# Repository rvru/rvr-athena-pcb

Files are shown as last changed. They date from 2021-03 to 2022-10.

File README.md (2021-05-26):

# RVR Athena PCB
**Contributor(s):** Jennifer Hellar 

**Contact(s):** jennifer.hellar@rice.edu

### Revisions
#### Rev. 0.1 (r0p1)
An initial (un-manufactured) design featuring a simplified version of the HiFive
reference design without the WiFi module and a new LiPo battery charger and
connector to enable IoT prototyping.

### Reference Designs
- SiFive HiFive Rev. B
- Sparkfun RED-V RedBoard
- Adafruit Feather M0 Bluefruit LE

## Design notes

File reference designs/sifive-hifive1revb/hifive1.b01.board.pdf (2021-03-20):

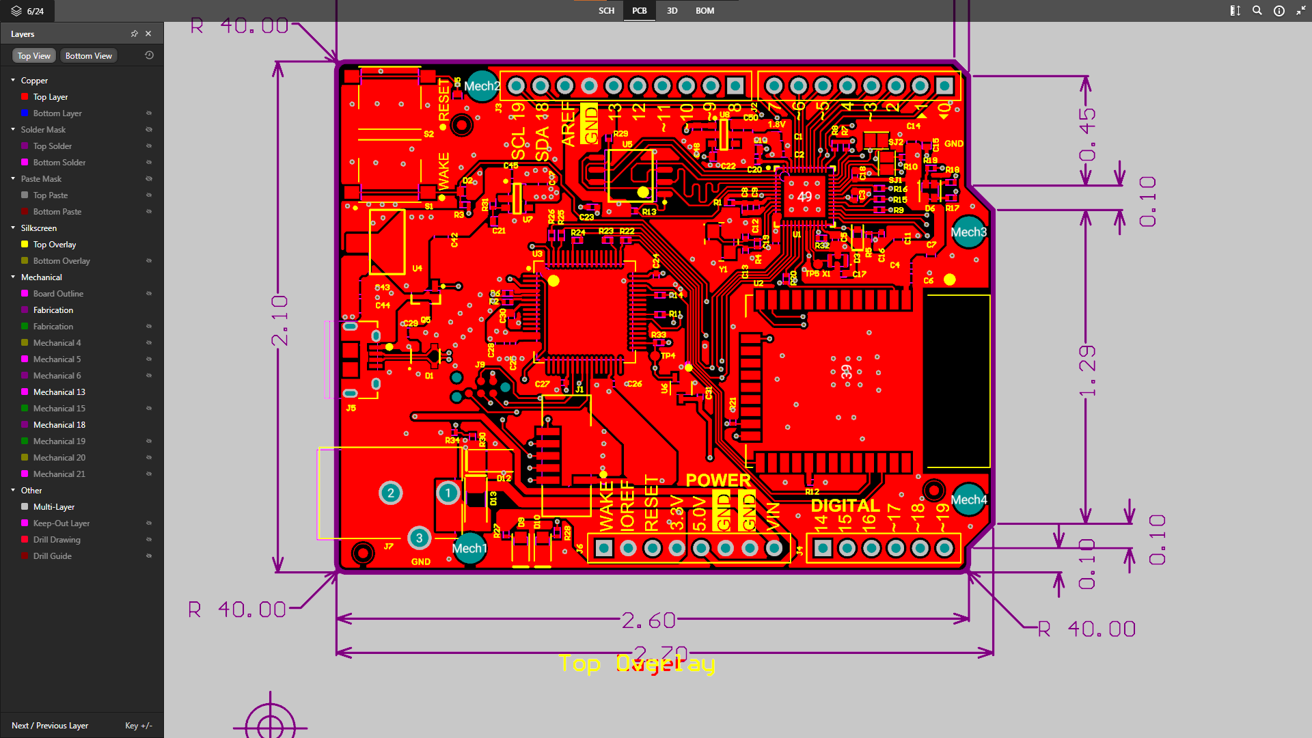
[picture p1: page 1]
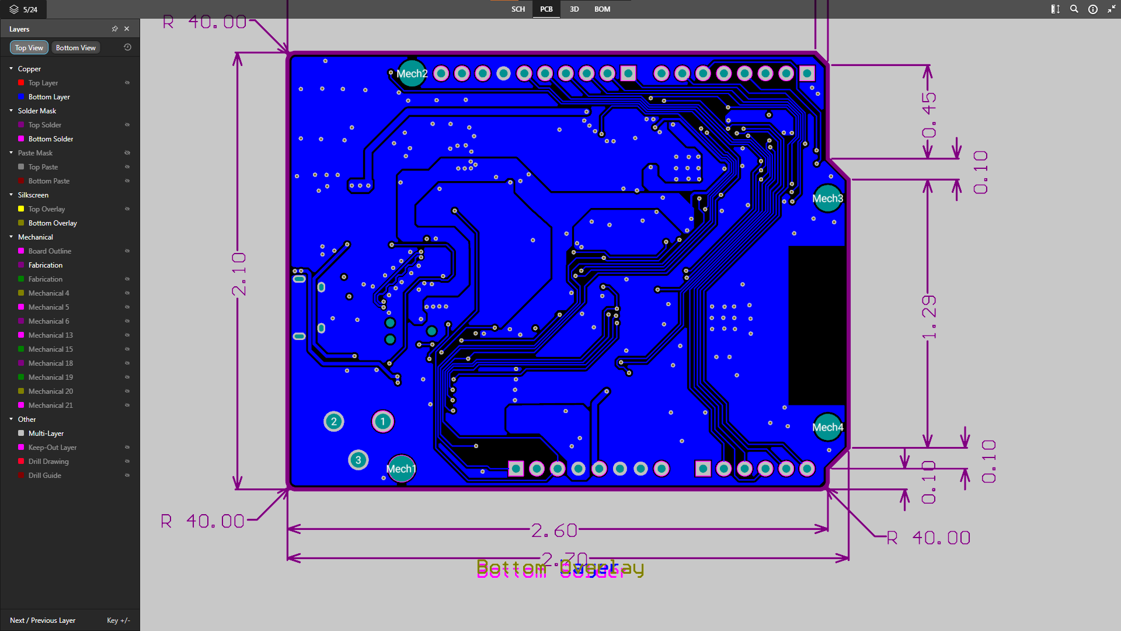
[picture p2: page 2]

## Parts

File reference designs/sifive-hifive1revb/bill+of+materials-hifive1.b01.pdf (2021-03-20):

Bill of Materials | HiFive1.B01.PrjPCB
Source Data From: | HiFive1.B01.PrjPCB
Project: | | HiFive1.B01.PrjPCB
Variant: | | None
Creation Date: 28-Feb-19 | 16:40:37
Print Date: | 15-Mar-19 | 1:10:20 AM
Item # | Quantity 10 | Manufacturer Murata | Manufacturer PN | Description | Value | Designator 1
| | Electronics | GRM188R61A106KE69J | CAP CER 10UF 10V X5R 0603 | 10uF | C1, C6, C7, C10, C11, C14, C15, C22, C28, C29
2 | 17 | Samsung Electro-Mechanics | CL05B104KO5NFNC | 0.10µF 16V Ceramic Capacitor X7R 0402 | 0.1uF | C2, C3, C4, C5, C8, C9, C17, C18, C19, C20, C23, C24, C25, C26, C27, C30, C31
3 | 2 | Yageo | CC0402JRNPO9BN150 | CAP CER 15PF 50V C0G/NPO 0402 | 15pF | C12, C13
4 | 1 | Samsung Electro-Mechanics | CL05B103KB5VPNC | CAP CER 10000PF 50V X7R 0402 | 10nF | C16
5 | 1 | Murata Electronics | GRM21BR60J226ME39L | 22µF 6.3V Ceramic Capacitor X5R 0805 | 22uF | C42
6 | 2 | Murata Electronics | GRM21BR61E106KA73L | 10µF ±10% 25V Ceramic Capacitor X5R 0805 | 10uF | C43, C44
7 | 4 | Murata Electronics | GRM188R61C105KA93D | 1µF 16V Ceramic Capacitor X5R 0603 | 1uF | C45, C47, C48, C50
8 | 1 | Nexperia | PRTR5V0U2X,215 | TVS DIODE 5.5V SOT143B | PRTR5V0U 2X,215 | D1
9 | 2 | Littlefuse | PESD0603-240 | TVS Diode 24VWM 45VClamp | PESD0603-240 | D2, D5
10 | 1 | Diodes Incorporated | 1N4148WT-7 | Diode Standard 80V 125mA Surface Mount SOD-523 | 1N4148WT- 7 | D3
11 | 1 | Lite-on Inc. | LTST-C19HE1WT | Red, Green, Blue (RGB) 624nm Red, 525nm Green, 470nm Blue LED Indication - Discrete 1.8V Red, 2.8V Green, 2.8V Blue 0606 | RGB | D6
12 | 2 | OSRAM Opto Semiconductors Inc | LG R971-KN-1 | Green 570nm LED Indication - Discrete 2.2V 0805 | Green | D9, D10
13 | 1 | Littelfuse Inc | SMF12A | TVS DIODE 12VWM 19.9VC SOD123 | SMF12A | D12
14 | 1 | Panasonic Electronic Components | DB2W40300L | Diode Schottky 40V 3A (DC) Surface Mount | DB2W4030 0L | D13
15 | 1 | CNC Tech | 3221-10-0300-00 | Connector Header Surface Mount 10 position 0.050" (1.27mm) | | J1
16 | 2 | Sullins Connector Solutions | PPTC081LFBN-RC | 8 Pin I/O Connector | | J2, J6
17 | 1 | Sullins Connector Solutions | PPTC101LFBN-RC | 10 Pin Connector | | J3
18 | 1 | Sullins Connector Solutions | PPTC061LFBN-RC | 6 Pin Connector | | J4
19 | 1 | Amphenol FCI | 10118194-0001LF | USB - micro B USB 2.0 Receptacle Connector 5 Position Surface Mount, Right Angle, Horizontal | | J5
20 | 1 | CUI Inc | PJ-102AH | Power Barrel Connector Jack 2.00mm ID (0.079"), 5.50mm OD (0.217") Through Hole, Right Angle | | J7
21 | 1 | Diodes Inc | DMG2305UX-13 | MOSFET P-CH 20V 4.2A SOT23 | P-Channel | Q5
22 | 8 | Yageo | RC0402FR-07100RL | RES SMD 100 OHM 1% 1/16W 0402 | 100R | R1, R11, R14, R22, R23, R24, R25, R26
23 | 2 | Yageo | RC0402FR-0733RL | RES SMD 33 OHM 1% 1/16W 0402 | 33R | R2, R6
24 | 9 | Yageo | RC0402FR-07100KL | RES SMD 100K OHM 1% 1/16W 0402 | 100K | R3, R5, R10, R13, R29, R30, R31, R33, R34
25 | 1 | Yageo | RC0402FR-071ML | RES SMD 1M OHM 1% 1/16W 0402 | 1M | R4
26 | 3 | Yageo | RC0402FR-0722RL | RES SMD 22 OHM 1% 1/16W 0402 | 22R | R9, R15, R16
27 | 2 | Yageo | RC0402FR-071KL | RES SMD 1K OHM 1% 1/16W 0402 | 1K | R12, R20
28 | 5 | Yageo | RC0402FR-07330RL | RES SMD 330 OHM 1% 1/16W 0402 | 330R | R17, R18, R19, R27, R28
29 | 1 | Yageo | RC0402FR-07150KL | RES SMD 150K OHM 1% 1/16W 0402 | 150K | R32
30 | 1 | C & K Components | PTS645SM43SMTR92 LFS | Blue Tactile Switch SPST-NO Top Actuated Surface Mount | | S1
31 | 1 | C & K Components | PTS645SK43SMTR92 LFS | Red Tactile Switch SPST-NO Top Actuated Surface Mount | | S2
32 | 1 | SiFive | FE310-G002 | SiFive Freedom E310 Microcontroller | FE310-G002 | U1
33 | 1 | Espressif Systems | ESP32-SOLO-1 | WiFi 802.11n + BT4.2 Chipset Module Single Core with PCB Antenna 18mmx25.5mm | ESP32-SOLO-1 | U2
34 | 1 | NXP USA Inc | MK22FN128VLH10 | K20 Microcontroller | MK22FN128 VLH10 | U3
35 | 1 | ON Semiconductor | NCP1117LPST50T3G | IC REG LINEAR 5V 1A SOT223 | NCP1117LP ST50T3G | U4
36 | 1 | ISSI | IS25LP032D-JBLE | IC FLASH 32MBIT 133MHZ 8SOIC 2.3 V ~ 3.6 V | 32Mbit | U5
37 | 1 | Microchip | MIC803-30D2VC3 | IC MPU SUPERVISOR SC70-3 | MIC803-30D2VC3 | U6
38 | 1 | Richtek USA | RT9080-33GJ5 | Linear Voltage Regulator IC Positive Fixed 1 Output 3.3V 600mA TSOT-23-5 | RT9080-33GJ5 | U7
39 | 1 | Richtek USA | RT9080-18GJ5 | Linear Voltage Regulator IC Positive Fixed 1 Output 1.8V 600mA TSOT-23-5 | RT9080-18GJ5 | U8
40 | 1 | SiTime | SIT1533AI-H4-DCC-32.768E | 32.768kHz LVCMOS MEMS (Silicon) Oscillator Surface Mount 1.2 V ~ 3.63 V 1.3µA | 32.768KHz | X1
41 | 1 | Epson | TSX-3225 16.0000MF18X-AC0 | 16MHz ±10ppm Crystal 9pF 60 Ohm | 16MHz | Y1
Approved | Notes
Altium Limited Confidential | 3/15/2019 | Page 1

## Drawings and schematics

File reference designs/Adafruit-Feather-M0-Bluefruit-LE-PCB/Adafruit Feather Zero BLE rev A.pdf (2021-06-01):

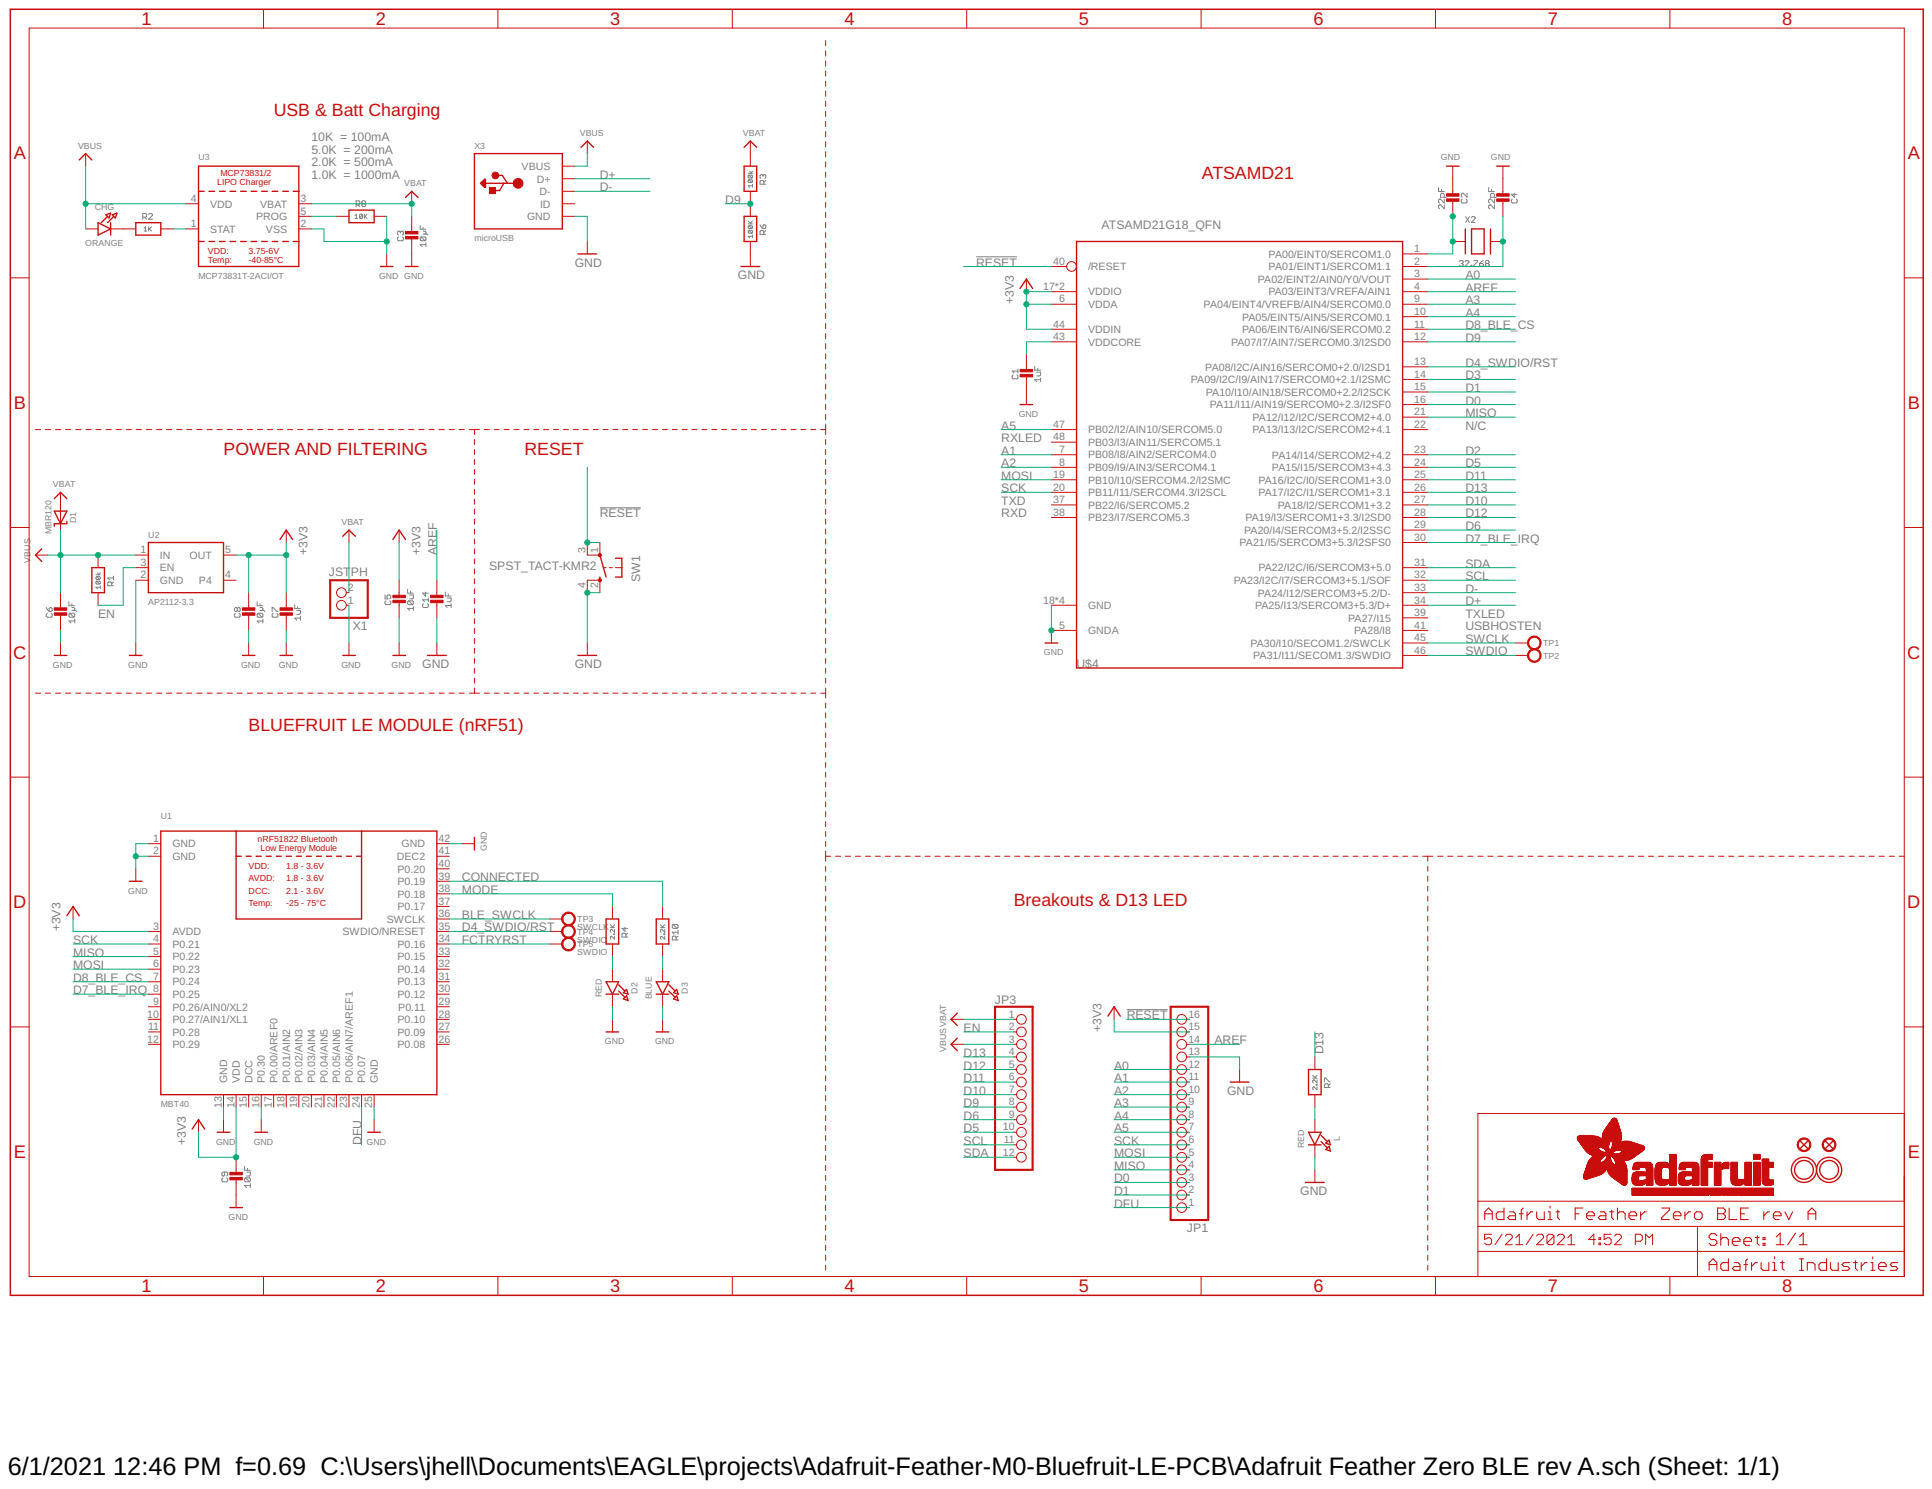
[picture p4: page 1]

6/1/2021 12:46 PM f=0.69 C:\Users\jhell\Documents\EAGLE\projects\Adafruit-Feather-M0-Bluefruit-LE-PCB\Adafruit Feather Zero BLE rev A.sch (Sheet: 1/1)

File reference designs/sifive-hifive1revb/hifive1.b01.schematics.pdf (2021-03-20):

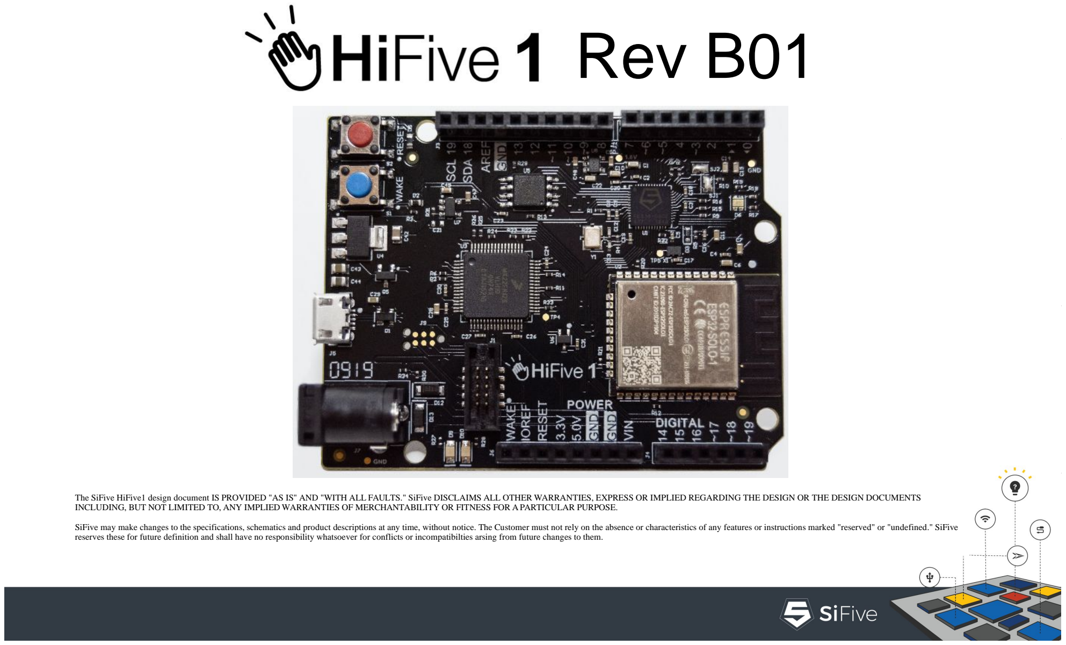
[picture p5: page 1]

The SiFive HiFive1 design document IS PROVIDED "AS IS" AND "WITH ALL FAULTS." SiFive DISCLAIMS ALL OTHER WARRANTIES, EXPRESS OR IMPLIED REGARDING THE DESIGN OR THE DESIGN DOCUMENTS
INCLUDING, BUT NOT LIMITED TO, ANY IMPLIED WARRANTIES OF MERCHANTABILITY OR FITNESS FOR A PARTICULAR PURPOSE.

SiFive may make changes to the specifications, schematics and product descriptions at any time, without notice. The Customer must not rely on the absence or characteristics of any features or instructions marked "reserved" or "undefined." SiFive
reserves these for future definition and shall have no responsibility whatsoever for conflicts or incompatibilties arsing from future changes to them.

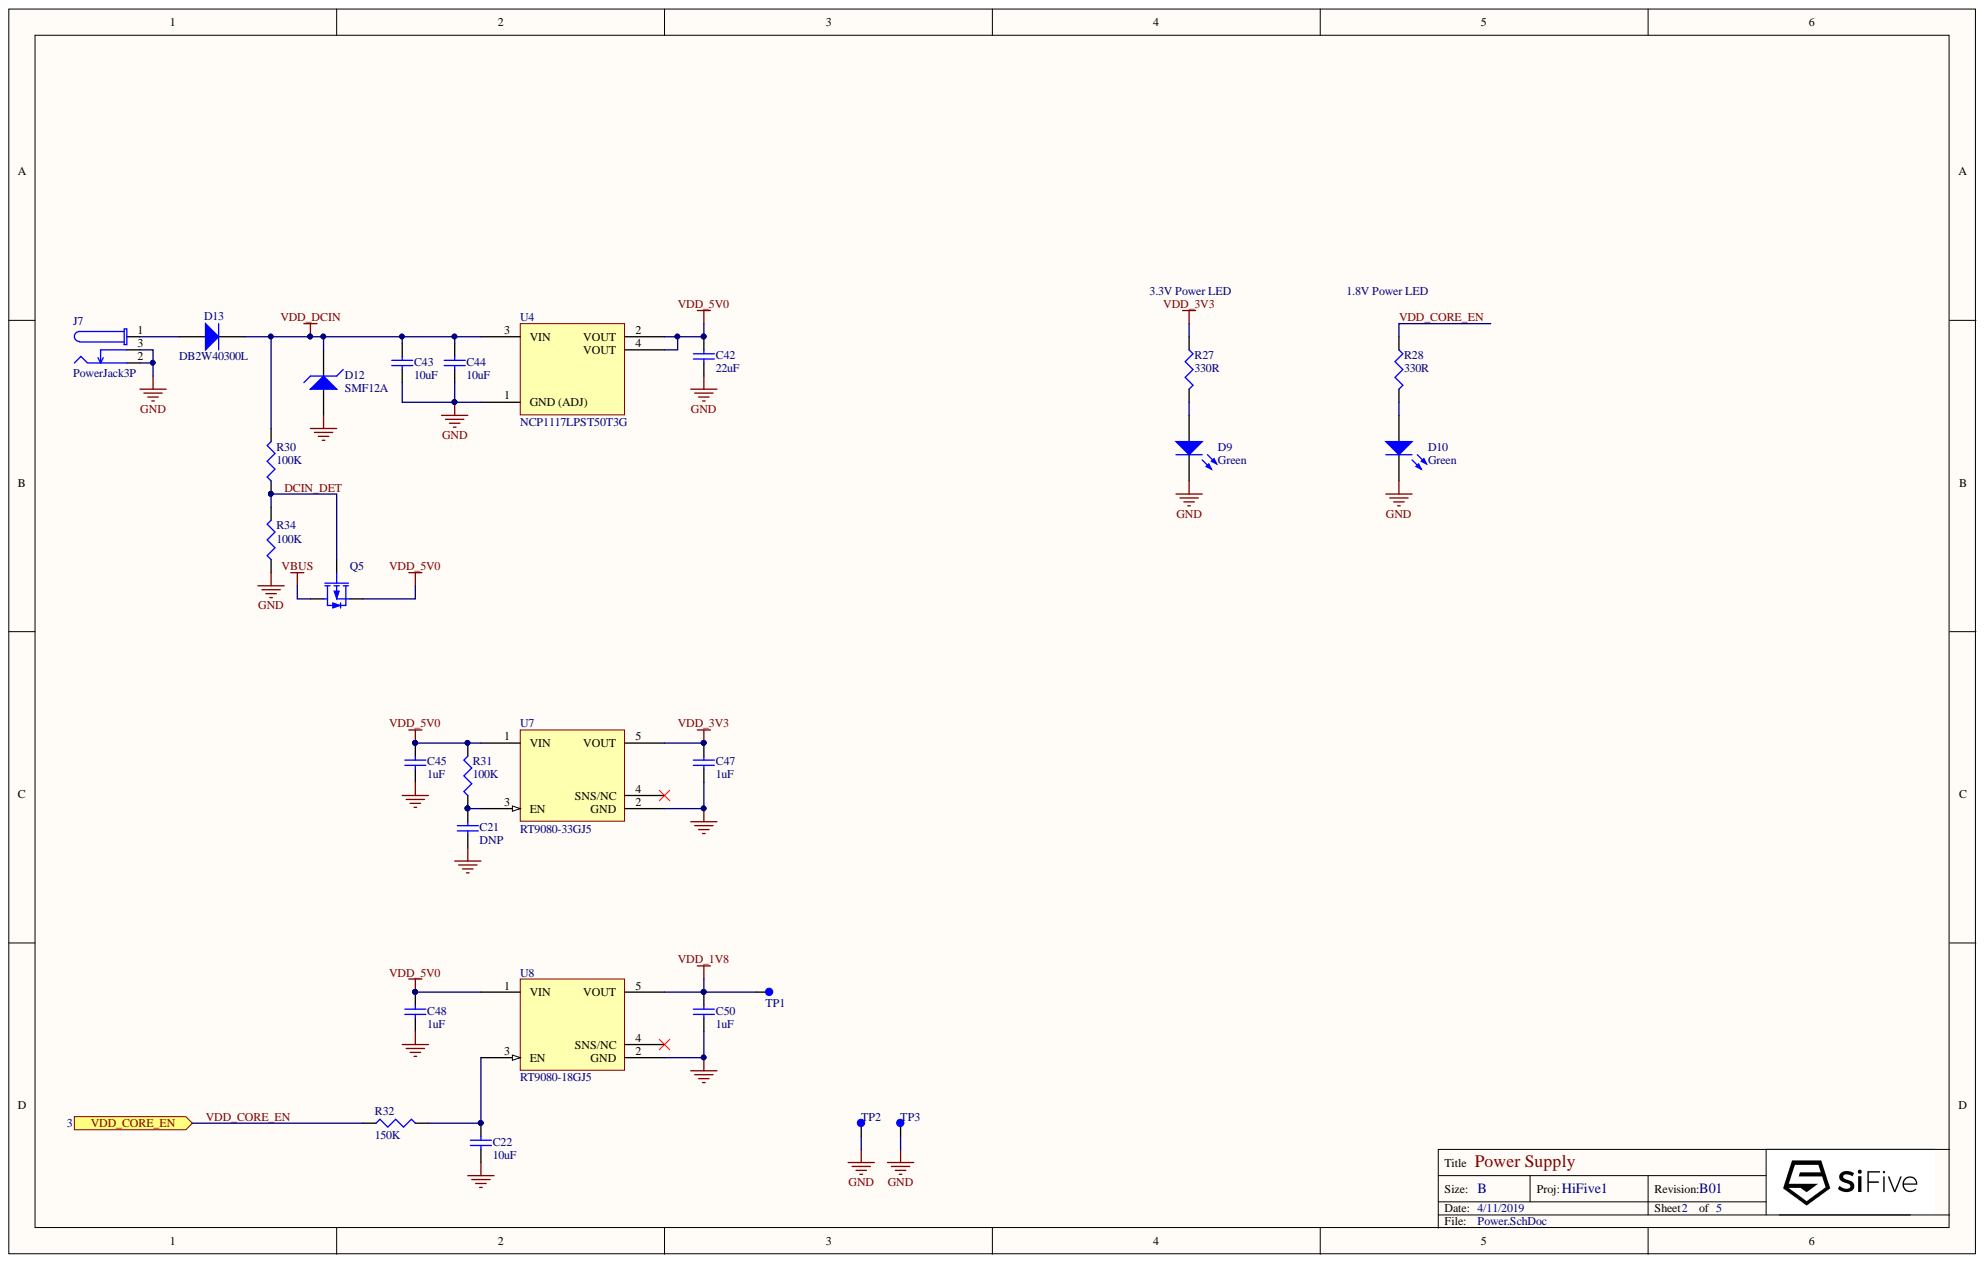
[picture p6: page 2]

Power Supply Title

B Size: | HiFive1 Proj: | B01 Revision:

Date: 4/11/2019 | | Sheet 2 of 5

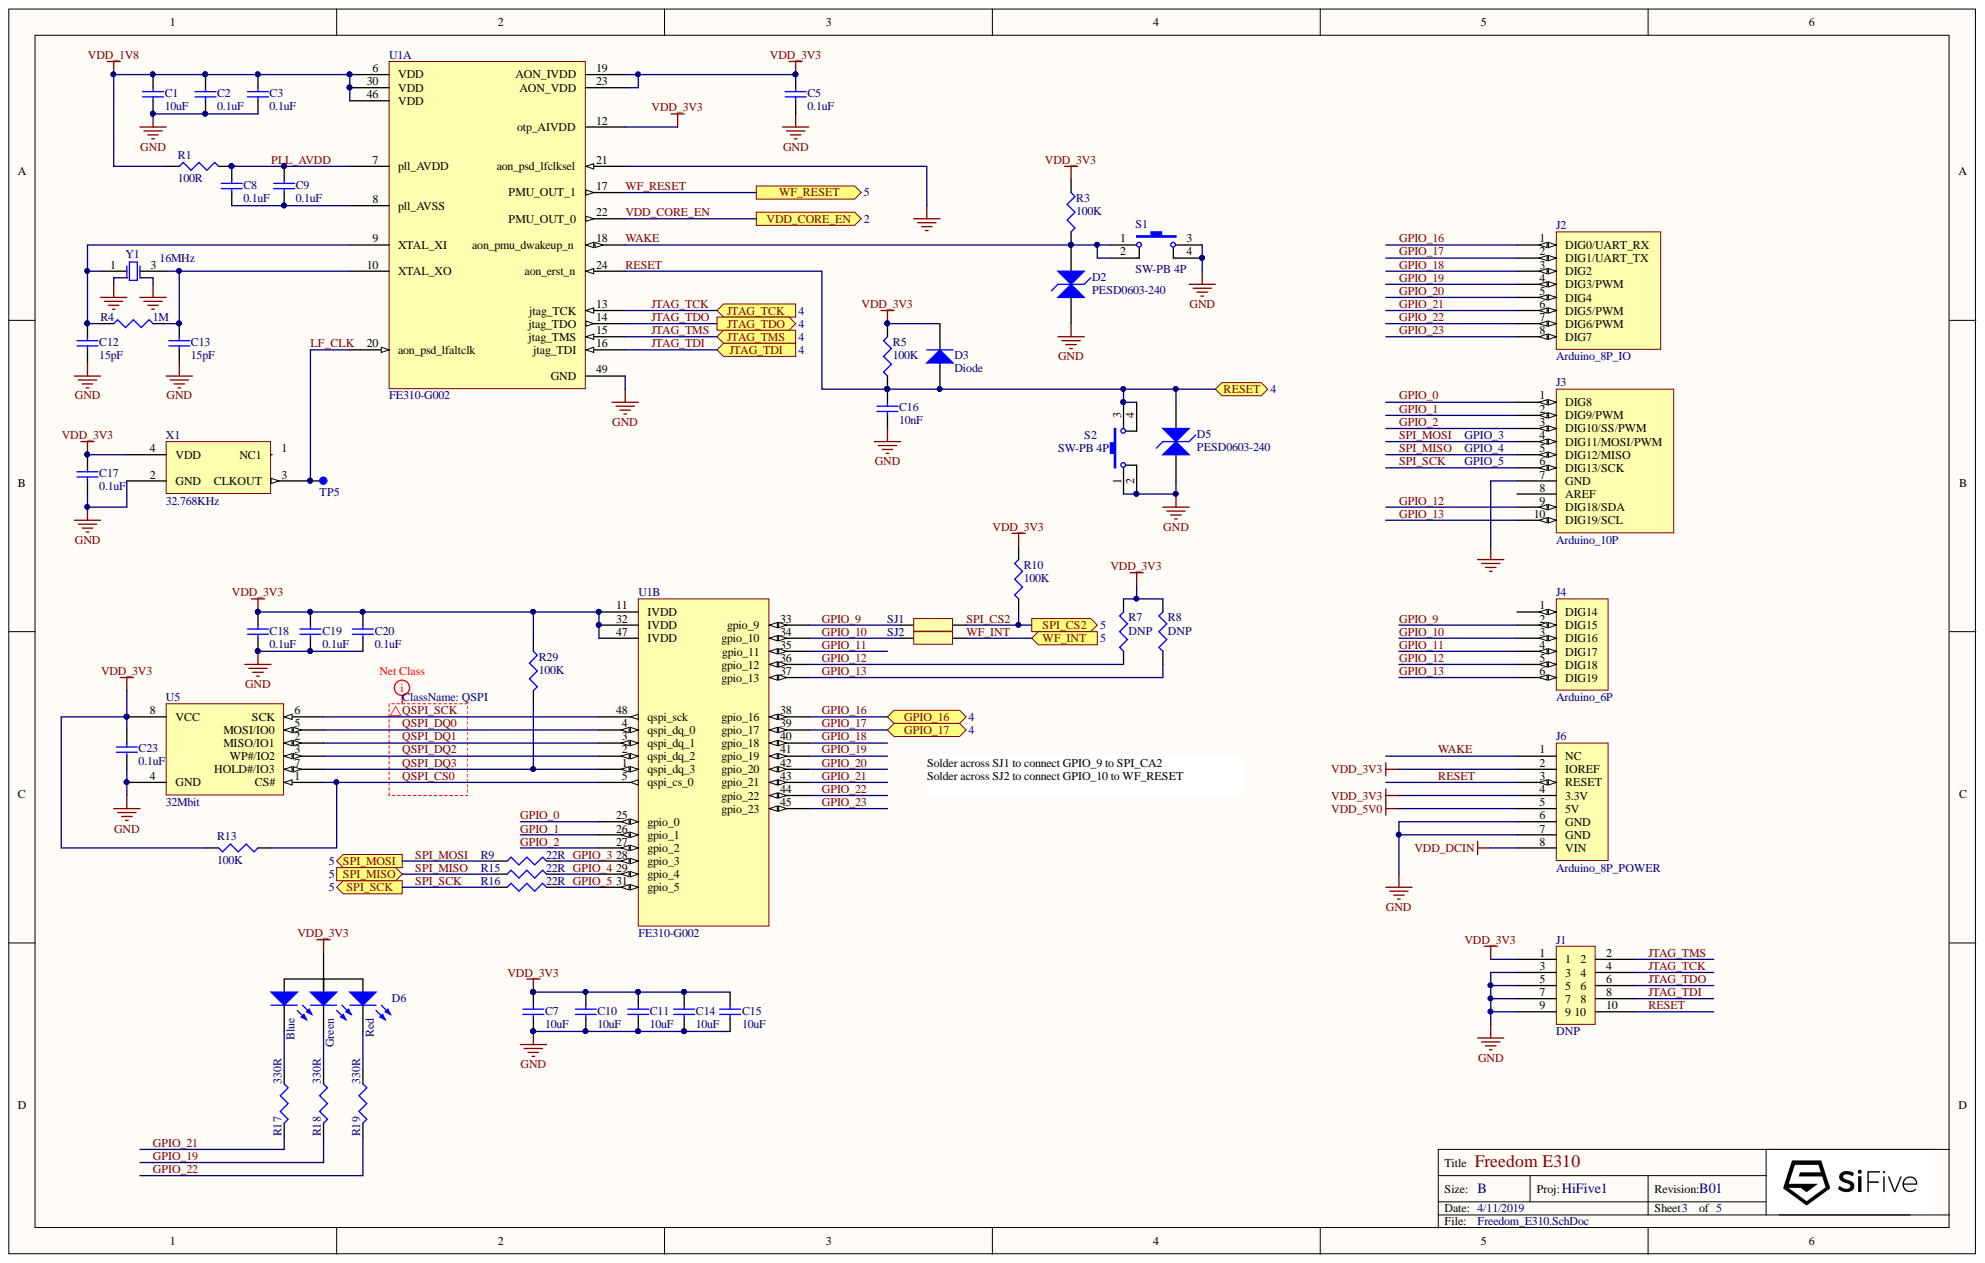
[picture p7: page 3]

0.1uF | | pll_AVDD 7 pll_AVSS 8

Solder across SJ1 to connect GPIO_9 to SPI_CA2
Solder across SJ2 to connect GPIO_10 to WF_RESET

gpio_0 25 gpio_1 26 gpio_2 27 gpio_3 28 gpio_4 29 gpio_5 31 | GPIO_22 | 3.3V 4

GPIO_23 | 5V 5

B Size: | HiFive1 Proj: | B01 Revision:

Date: 4/11/2019 | | Sheet 3 of 5

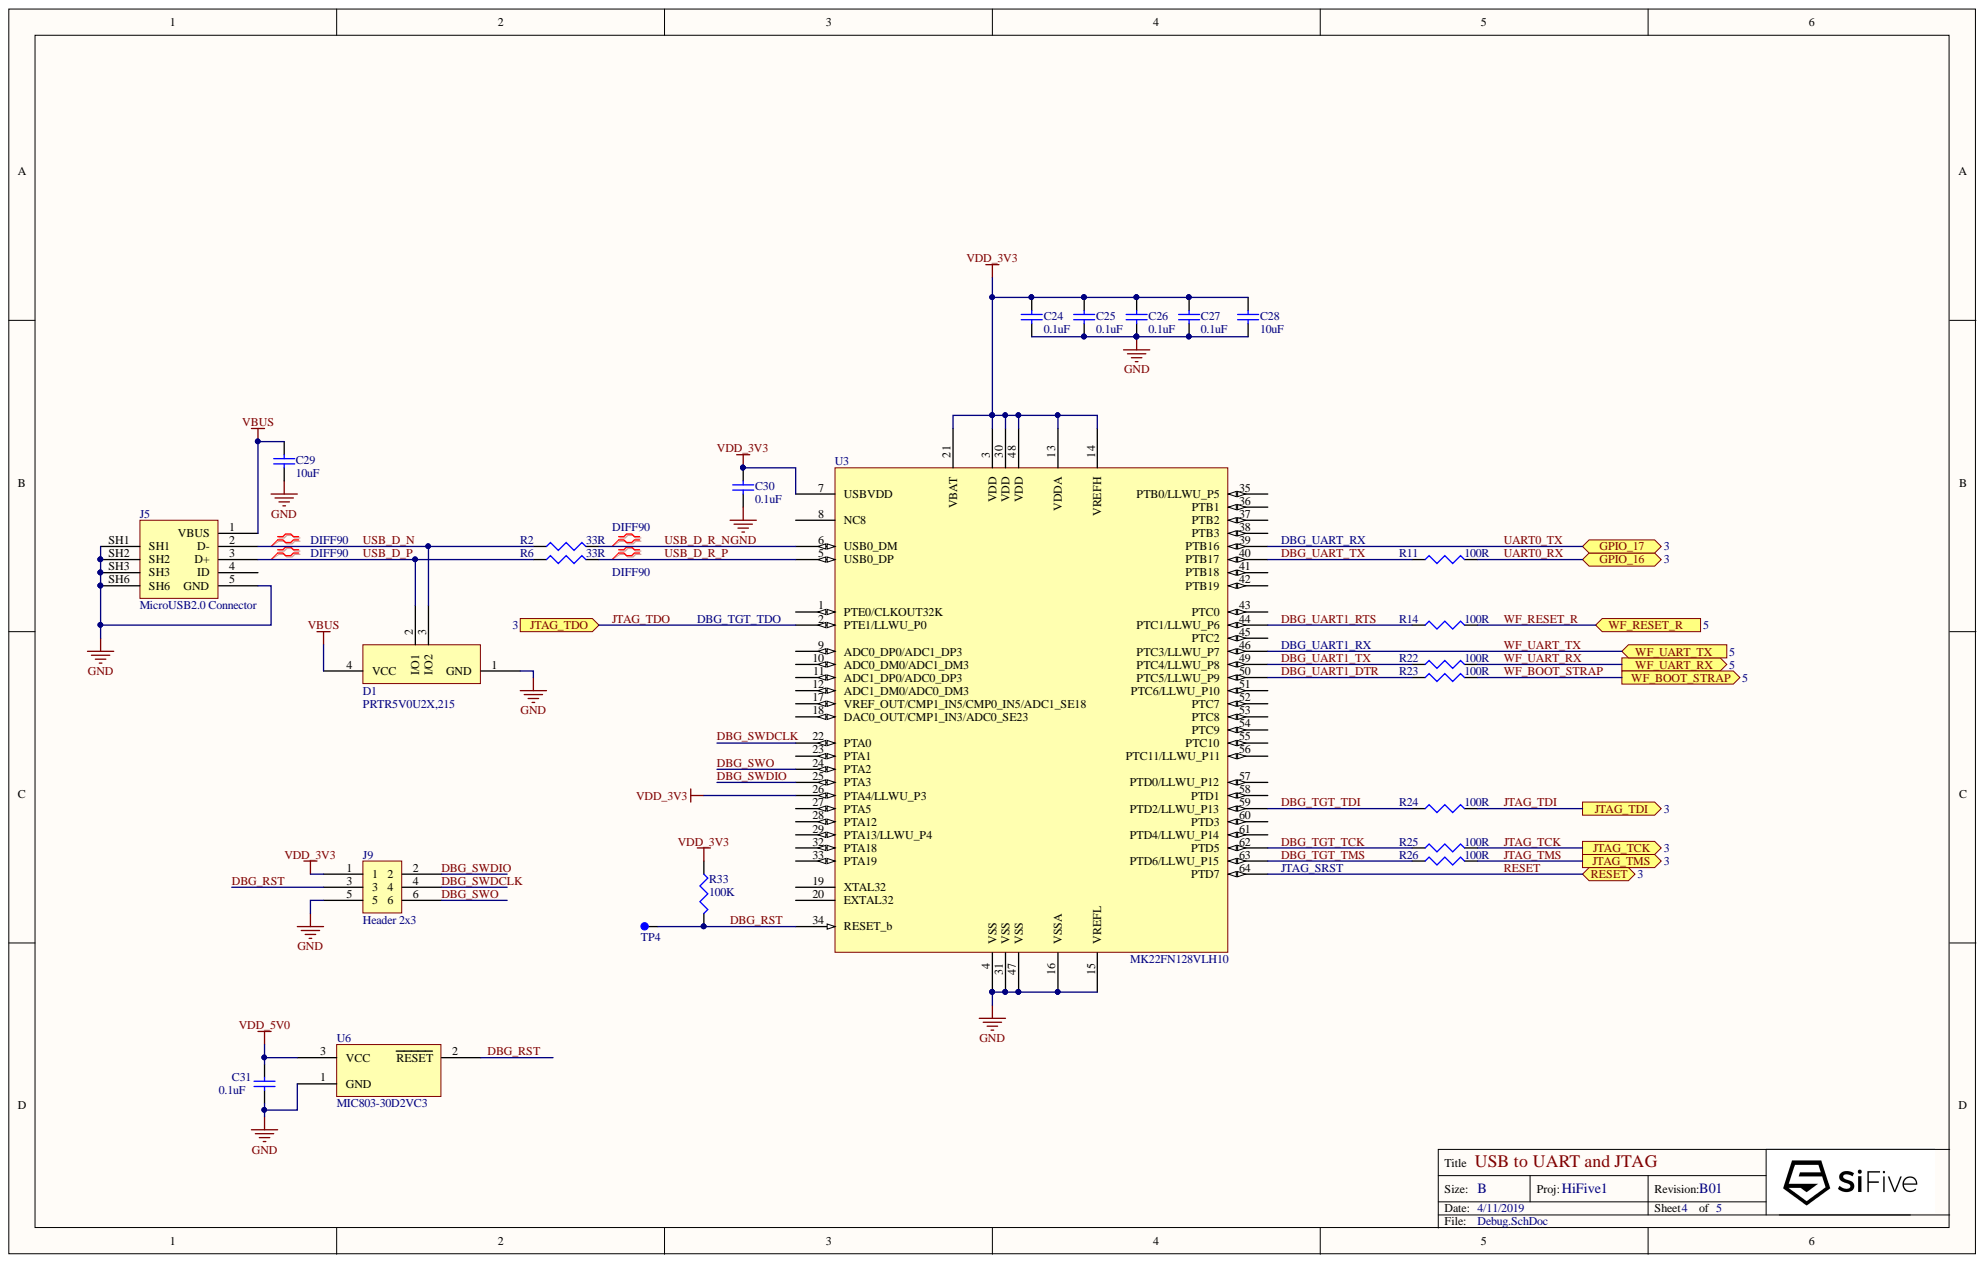
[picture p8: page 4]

USB to UART and JTAG Title

B Size: | HiFive1 Proj: | B01 Revision:

Date: 4/11/2019 | | Sheet 4 of 5

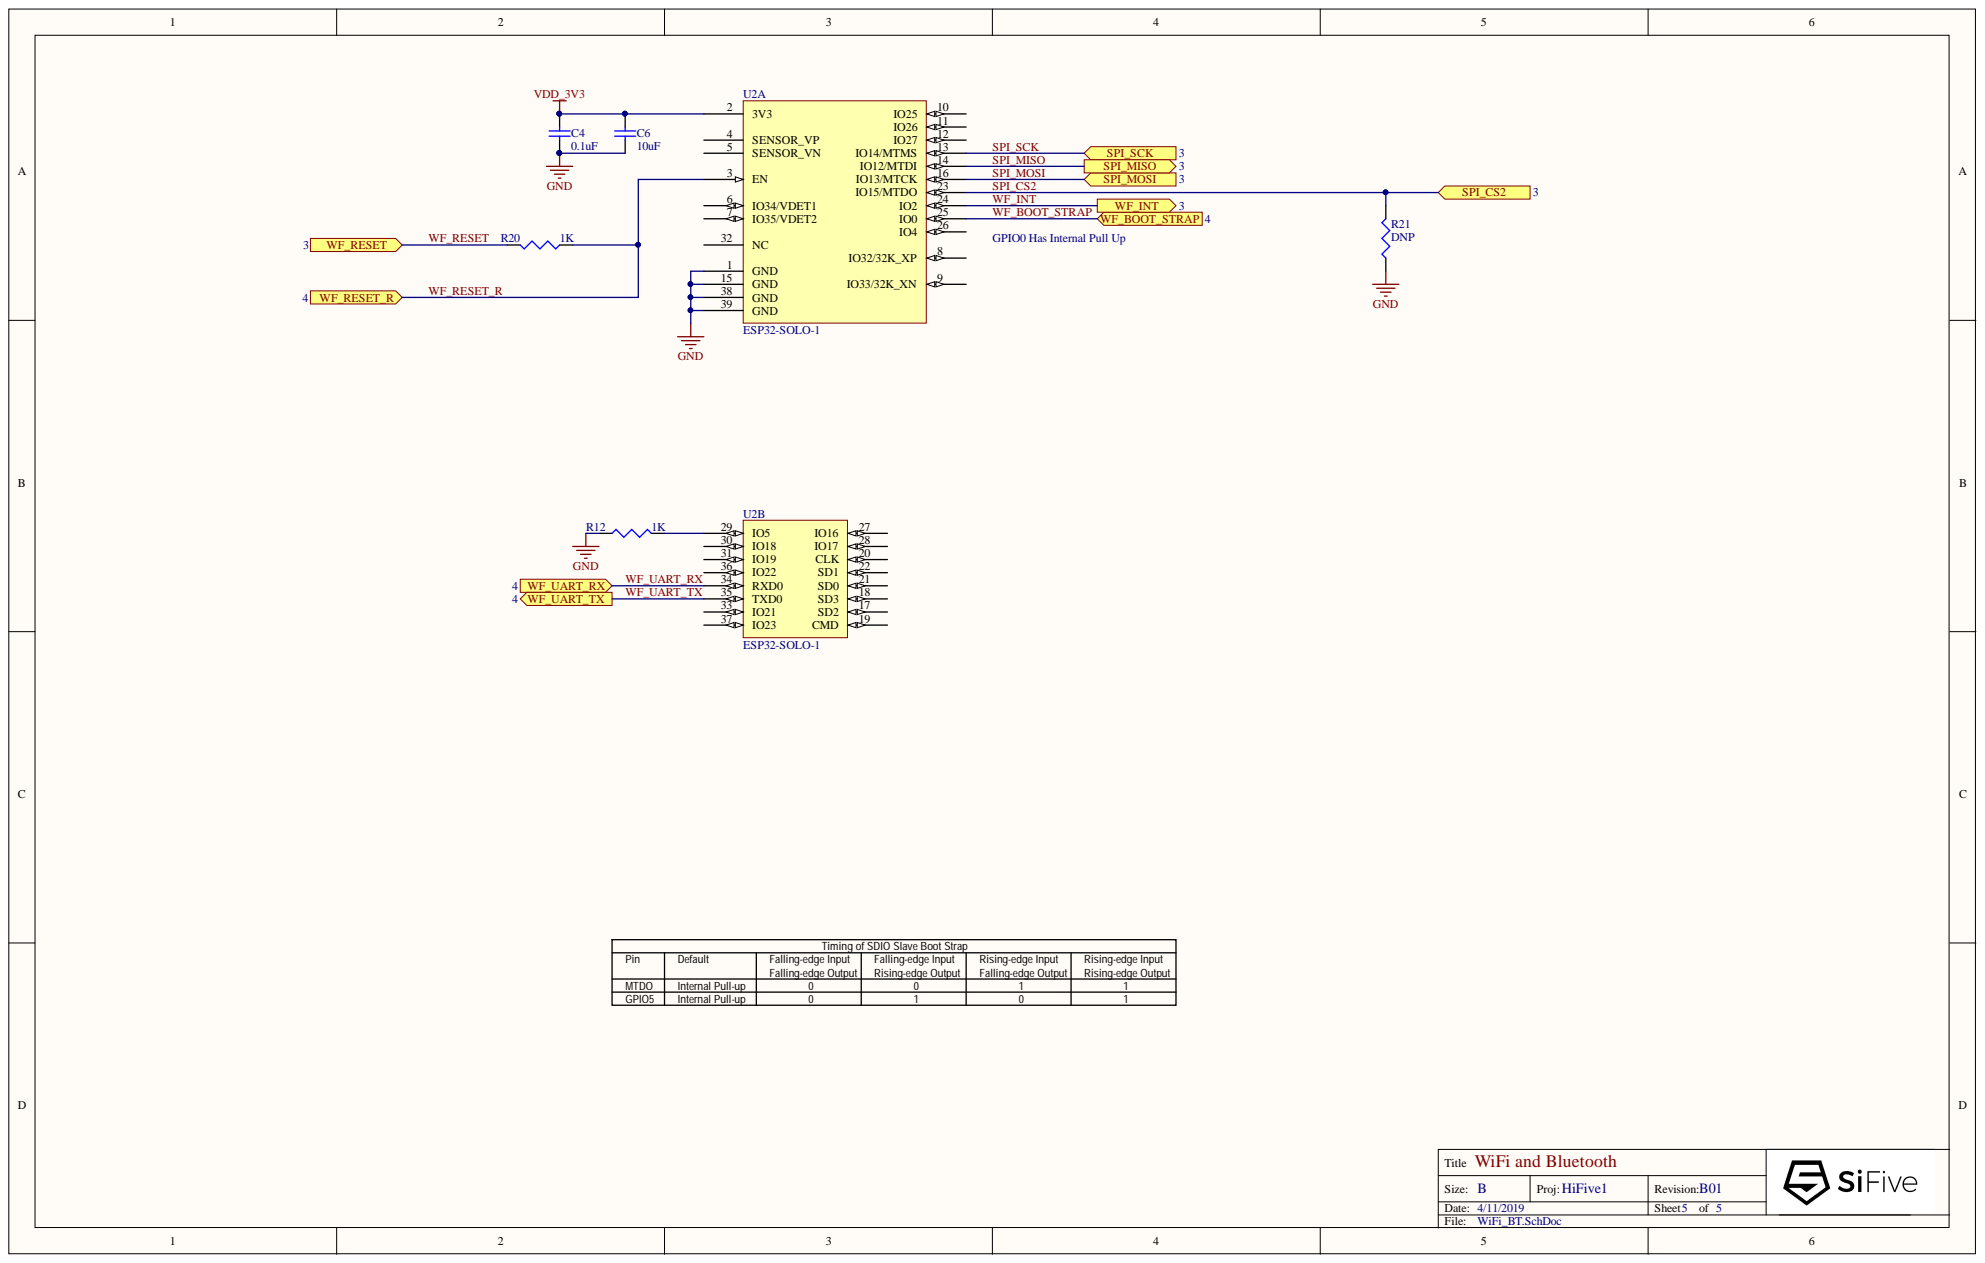
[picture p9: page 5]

GPIO0 Has Internal Pull Up

GND 1
GND 15
GND 38
GND 39

Timing of SDIO Slave Boot Strap

Pin | Default | Falling-edge Input Falling-edge Output | Falling-edge Input Rising-edge Output | Rising-edge Input Falling-edge Output | Rising-edge Input Rising-edge Output

MTDO | Internal Pull-up | 0 0 | | 1 1
GPIO5 | Internal Pull-up | 0 | 1 | 0 | 1

WiFi and Bluetooth Title

B Size: | HiFive1 Proj: | B01 Revision:

Date: 4/11/2019 | | Sheet 5 of 5

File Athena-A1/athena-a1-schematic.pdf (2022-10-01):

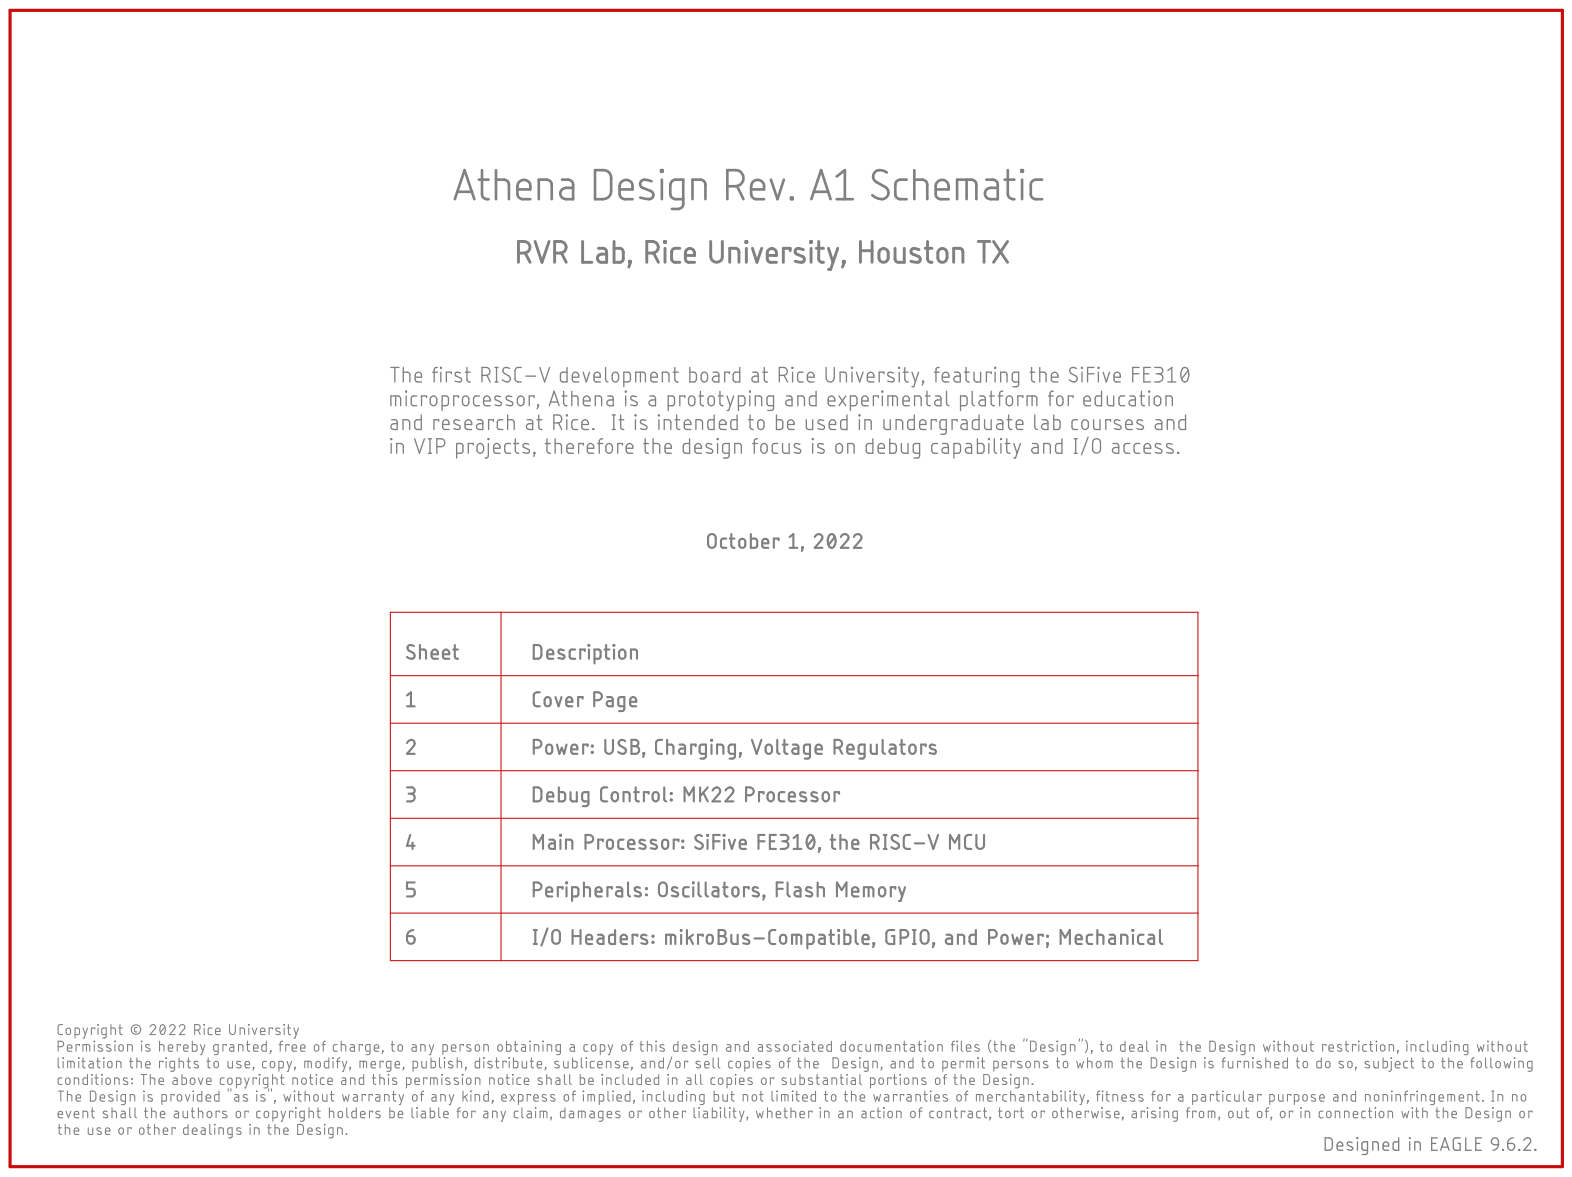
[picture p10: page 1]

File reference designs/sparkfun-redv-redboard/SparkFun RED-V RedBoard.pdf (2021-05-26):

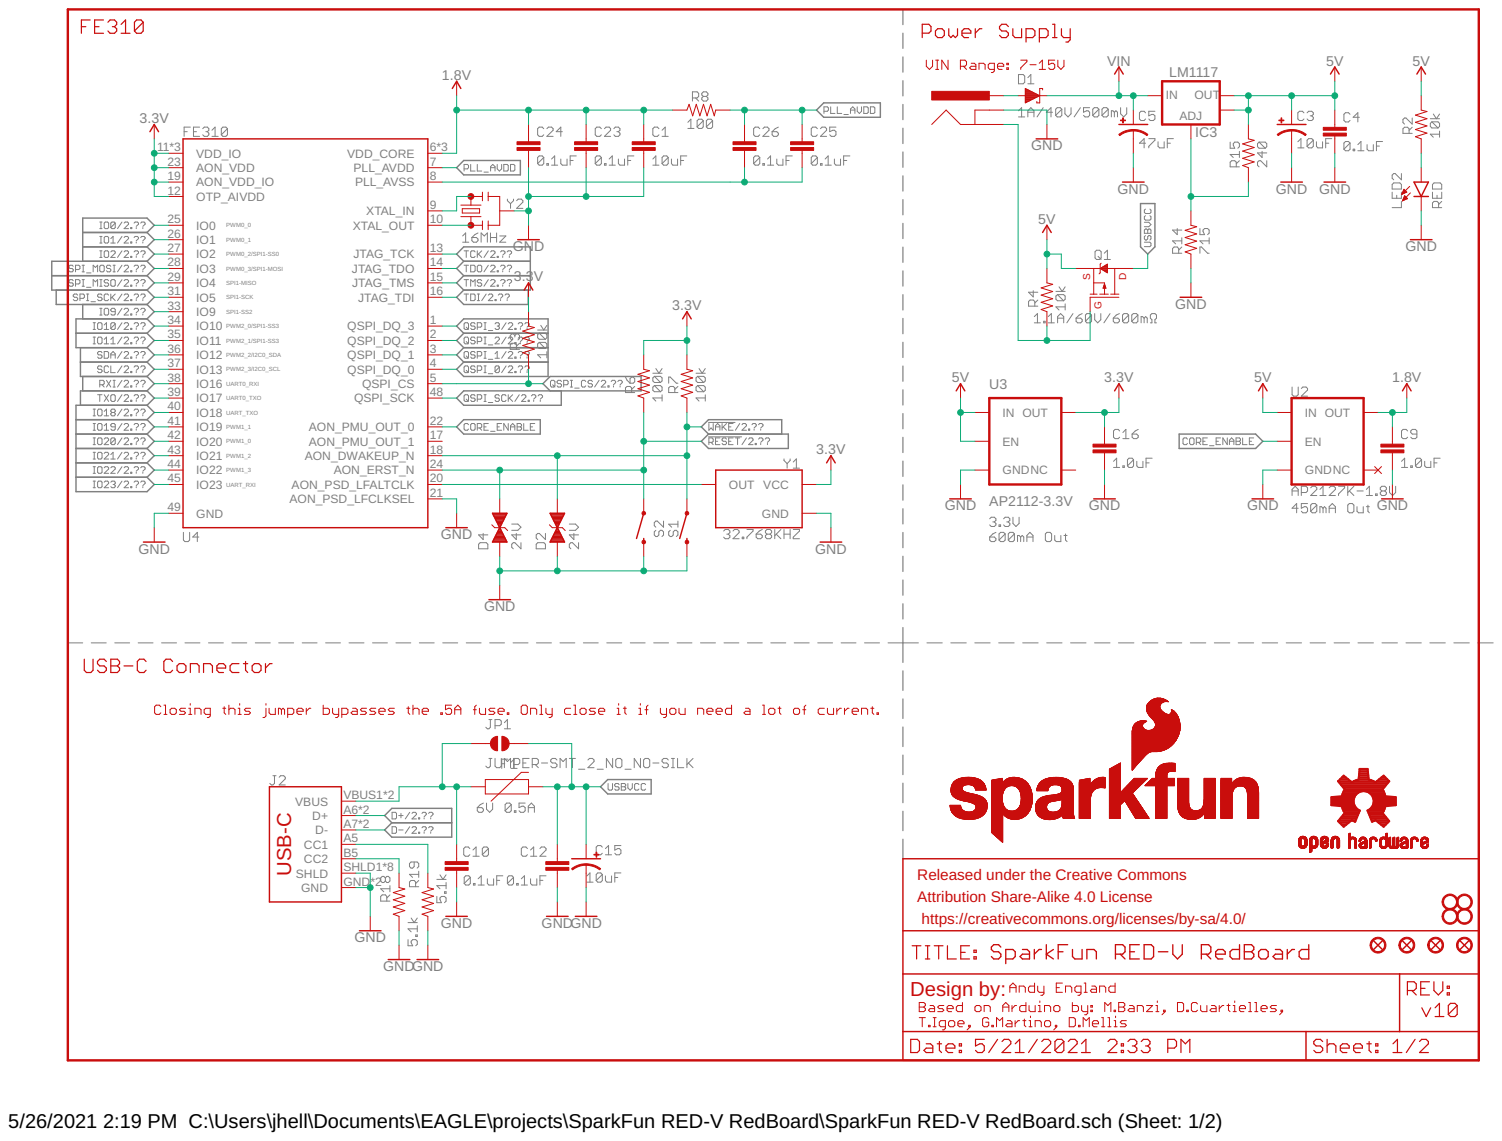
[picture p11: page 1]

Released under the Creative Commons Attribution Share-Alike 4.0 License

https://creativecommons.org/licenses/by-sa/4.0/

5/26/2021 2:19 PM C:\Users\jhell\Documents\EAGLE\projects\SparkFun RED-V RedBoard\SparkFun RED-V RedBoard.sch (Sheet: 1/2)

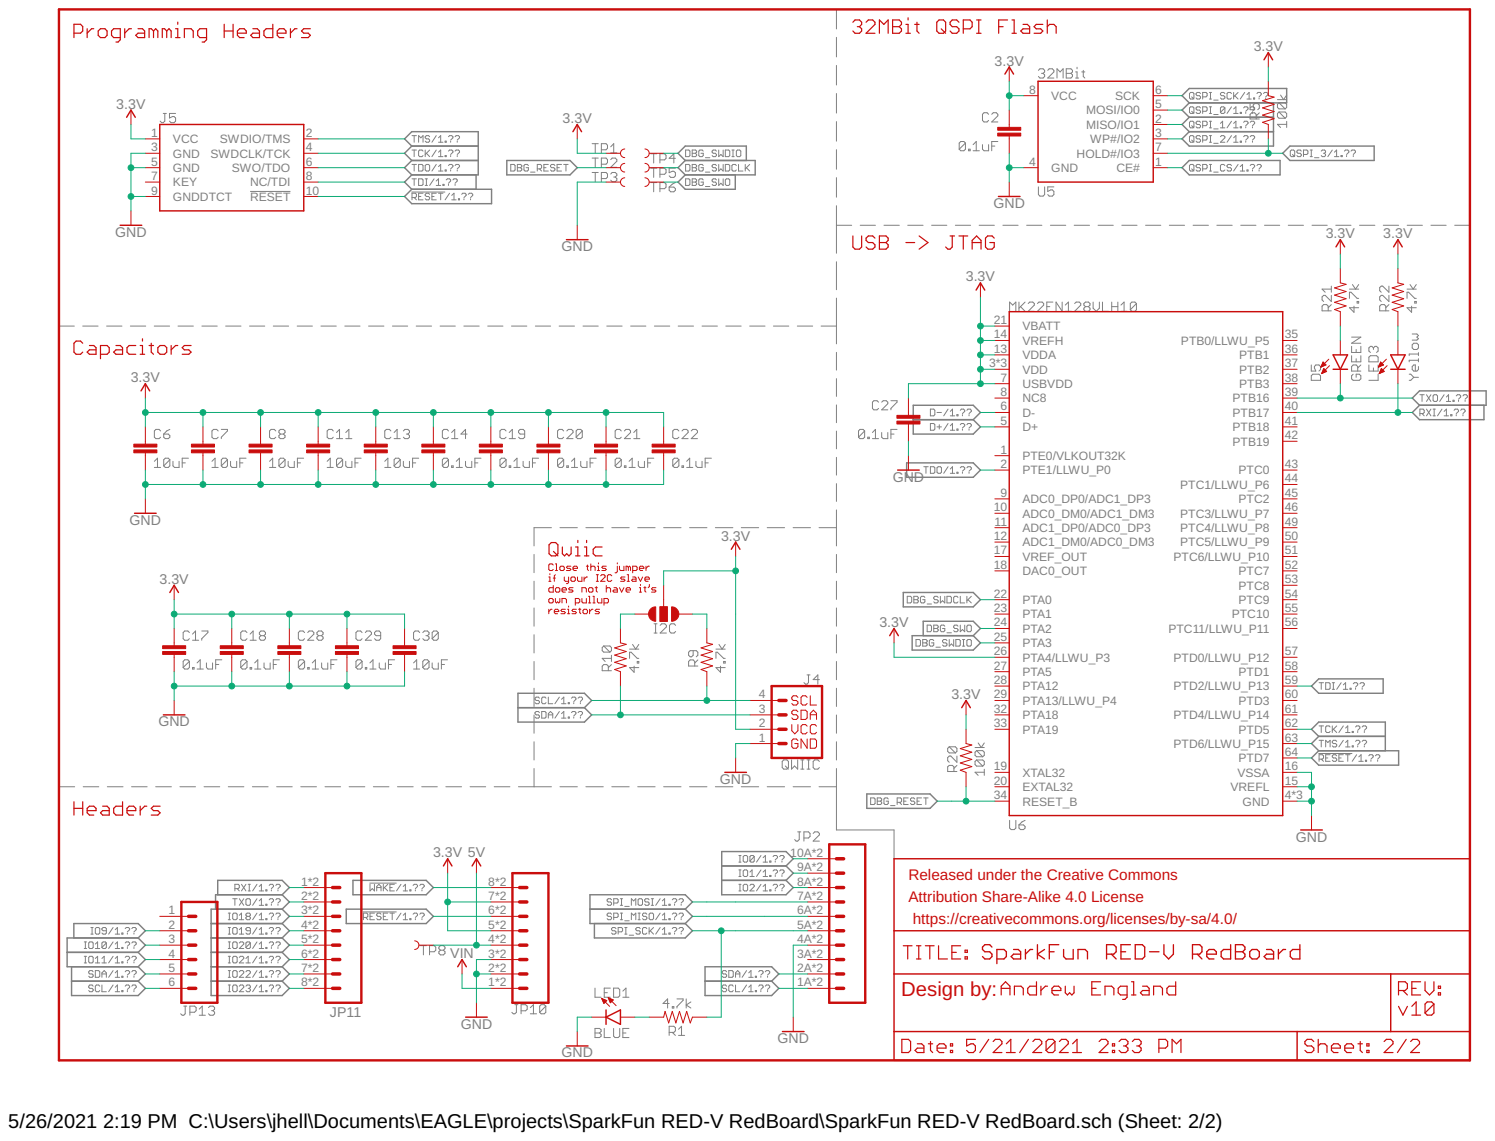
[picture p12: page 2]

Released under the Creative Commons Attribution Share-Alike 4.0 License

https://creativecommons.org/licenses/by-sa/4.0/

5/26/2021 2:19 PM C:\Users\jhell\Documents\EAGLE\projects\SparkFun RED-V RedBoard\SparkFun RED-V RedBoard.sch (Sheet: 2/2)

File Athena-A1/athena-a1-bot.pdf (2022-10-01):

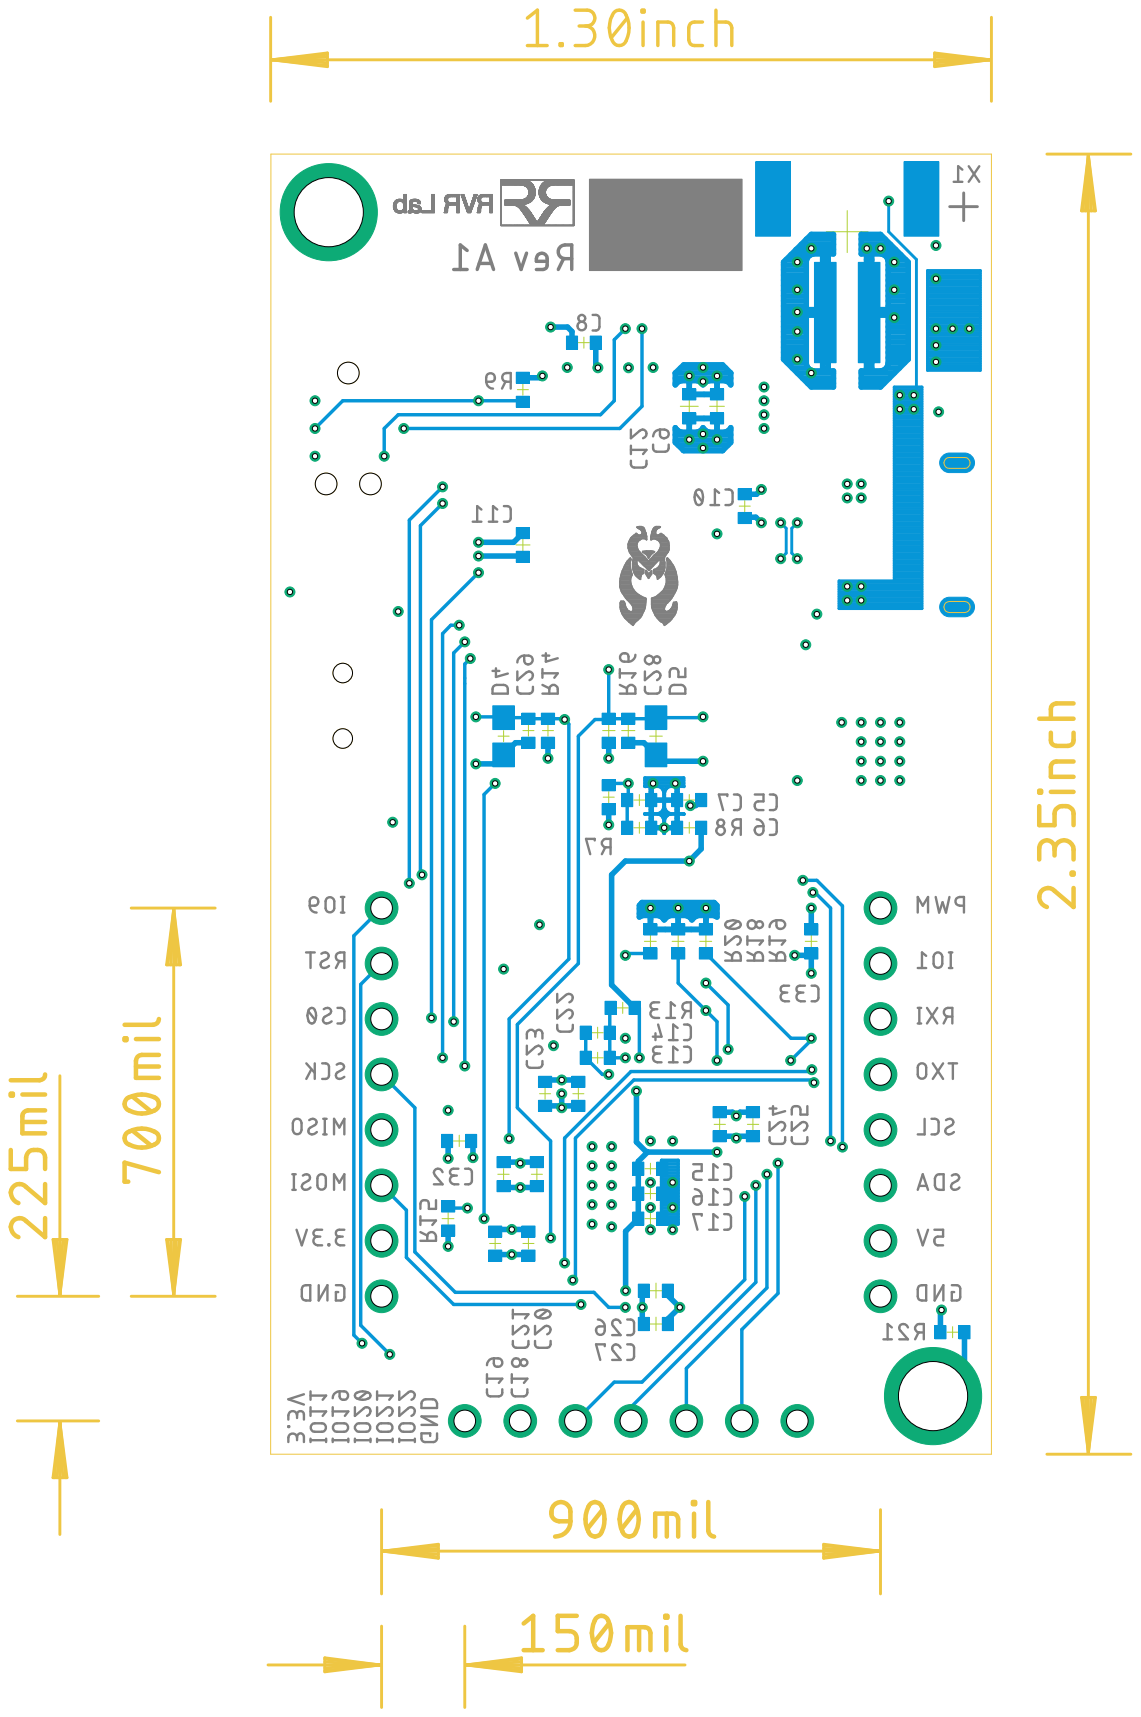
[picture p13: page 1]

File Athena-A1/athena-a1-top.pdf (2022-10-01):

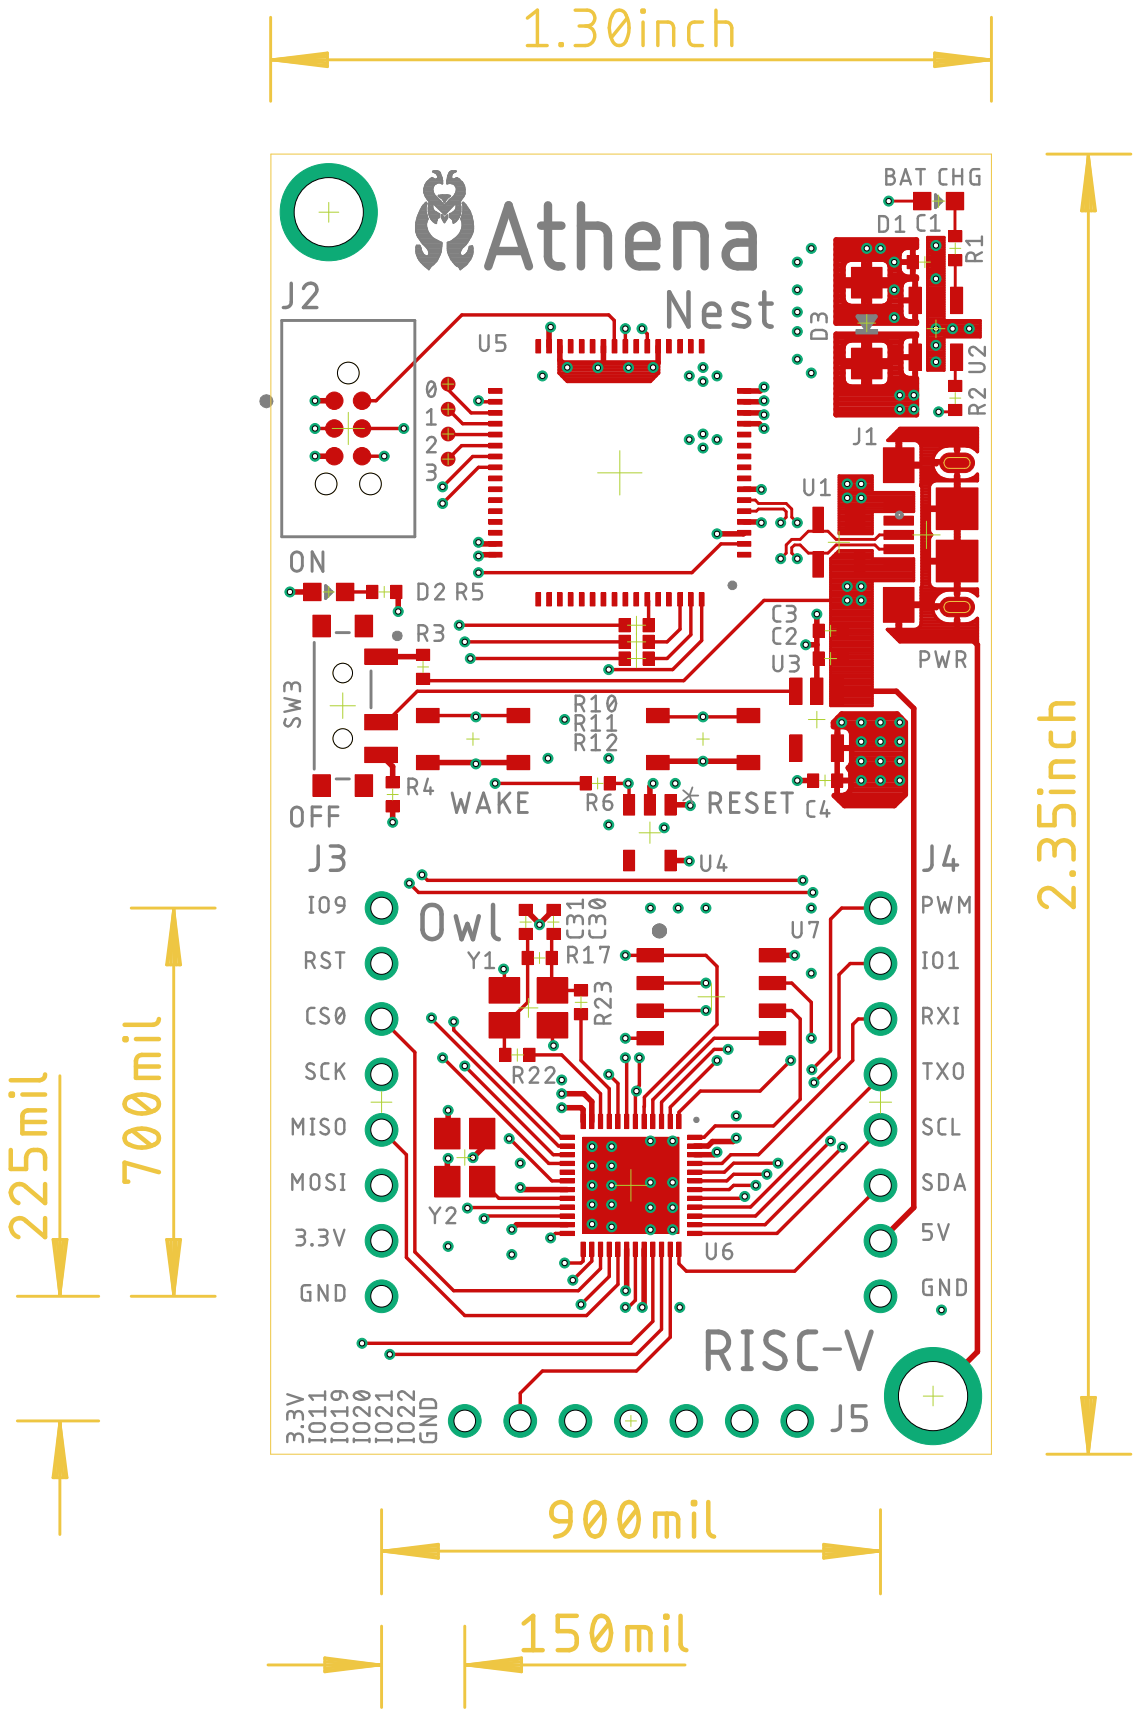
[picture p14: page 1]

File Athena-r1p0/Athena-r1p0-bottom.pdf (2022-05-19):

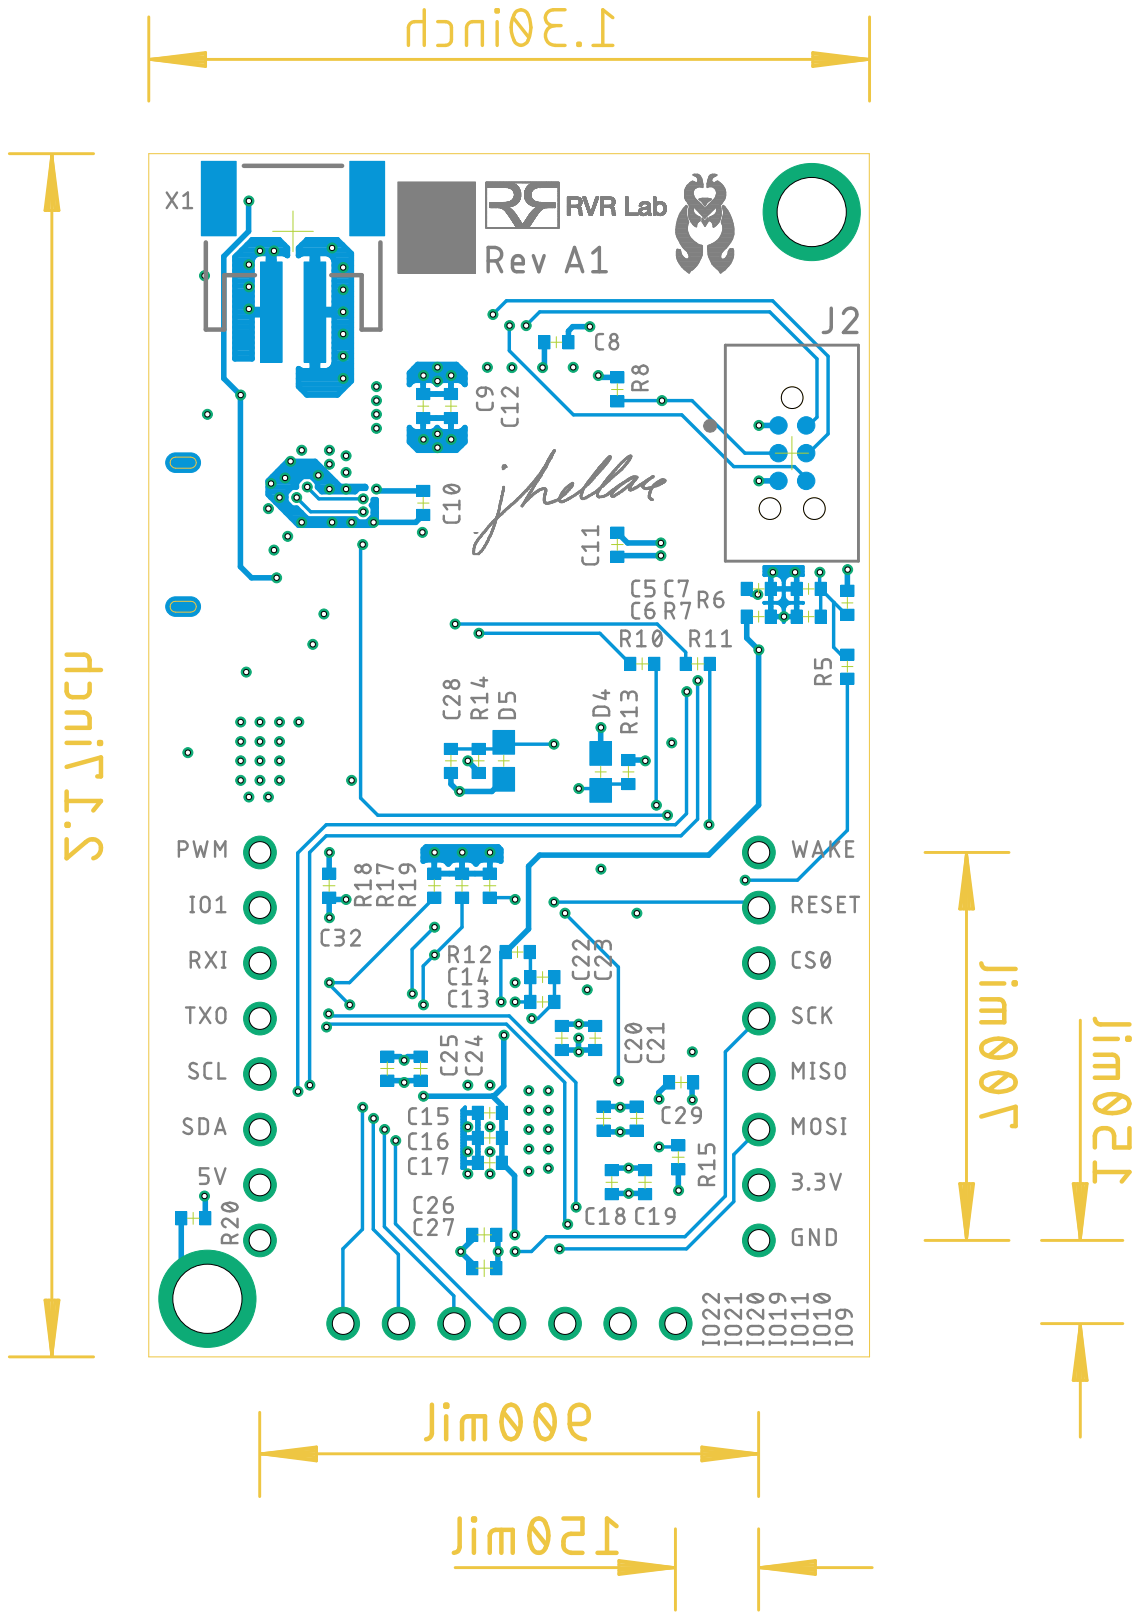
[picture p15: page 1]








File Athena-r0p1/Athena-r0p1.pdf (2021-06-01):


6/1/2021 5:34 PM C:\Users\jhell\Documents\EAGLE\projects\Athena-r0p1\Athena-r0p1.sch (Sheet: 1/5)


6/1/2021 5:34 PM C:\Users\jhell\Documents\EAGLE\projects\Athena-r0p1\Athena-r0p1.sch (Sheet: 2/5)


6/1/2021 5:34 PM C:\Users\jhell\Documents\EAGLE\projects\Athena-r0p1\Athena-r0p1.sch (Sheet: 3/5)


PLL_AVDD

6/1/2021 5:34 PM C:\Users\jhell\Documents\EAGLE\projects\Athena-r0p1\Athena-r0p1.sch (Sheet: 4/5)


6/1/2021 5:34 PM C:\Users\jhell\Documents\EAGLE\projects\Athena-r0p1\Athena-r0p1.sch (Sheet: 5/5)

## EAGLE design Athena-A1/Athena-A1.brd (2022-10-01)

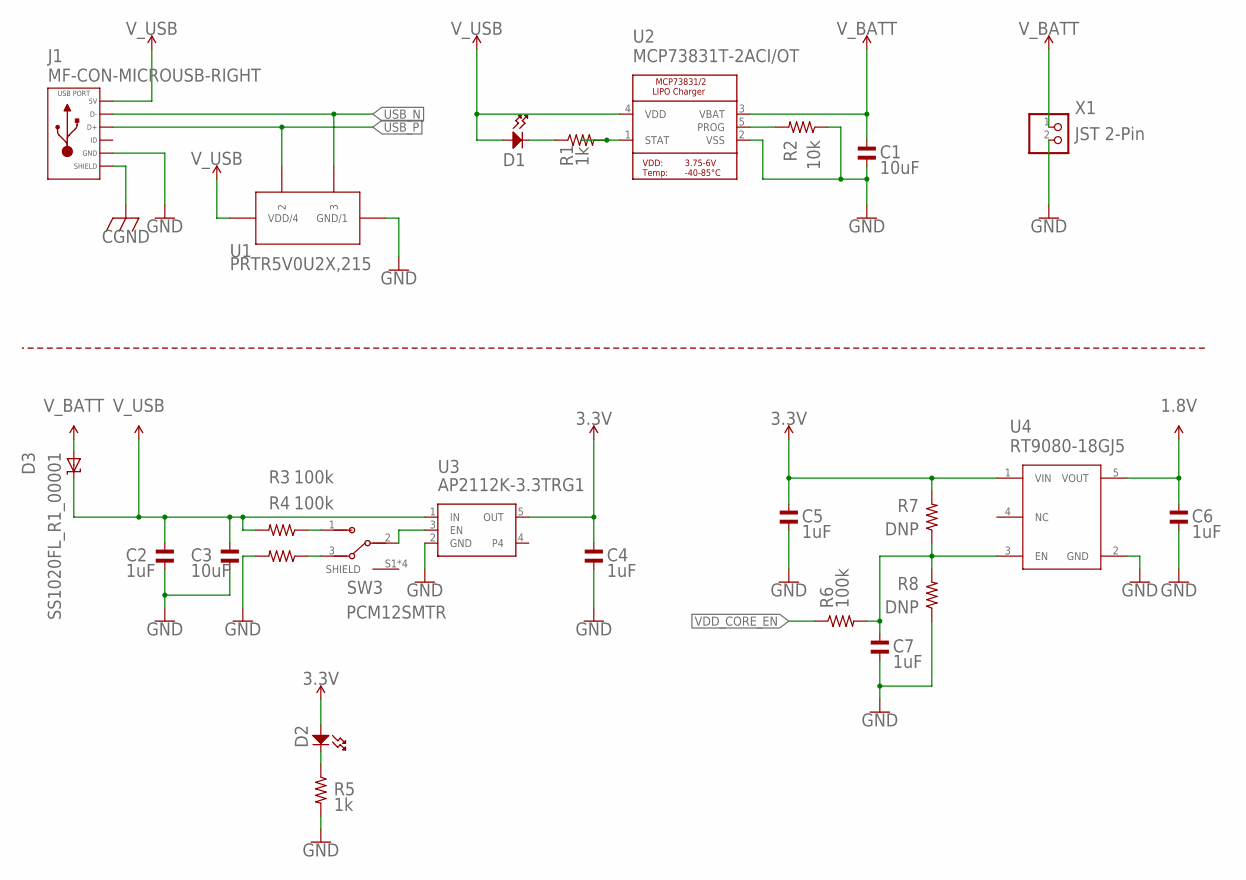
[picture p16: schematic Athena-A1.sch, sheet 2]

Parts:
C1, C3: 10uF; C0402; MPN CL05A106MP8NUB8
C2, C4, C5, C6, C7: 1uF; C0402
D1: MF-LED-0805-RED; LED0603
D2: MF-LED-0603-GREEN; LED0603
D3: SS1020FL_R1_00001; SOD-123
J1: MF-CON-MICROUSB-RIGHT; MICROUSB-RIGHT
R1, R5: 1k; R0402
R2: 10k; R0402
R3, R4, R6: 100k; R0402
R7, R8: DNP; R0402
SW3: PCM12SMTR; SW_PCM12SMTR
U1: PRTR5V0U2X,215; SOT143B_PRTR5V0U2X,215_NEX
U2: MCP73831T-2ACI/OT; SOT23-5
U3: AP2112K-3.3TRG1; SOT23-5
U4: RT9080-18GJ5; TSOT23-5_ONS
X1: JST 2-Pin; JSTPH2

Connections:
1.8V: C6.P$1, U4.5 (VOUT); also elsewhere on the board
3.3V: C4.P$1, C5.P$1, D2.ANODE, R7.P$2, U3.5 (OUT), U4.1 (VIN); also elsewhere on the board
CGND: J1.S1 (SLD), J1.S2 (SLD), J1.S3 (SLD), J1.S4 (SLD), J1.S5 (SLD), J1.S6 (SLD); also elsewhere on the board
GND: C1.P$2, C2.P$2, C3.P$2, C4.P$2, C5.P$2, C6.P$2, C7.P$2, J1.5 (GND), R2.P$1, R4.P$2, R5.P$2, R8.P$1, U1.1 (GND/1), U2.2 (VSS), U3.2 (GND), U4.2 (GND), X1.2; also elsewhere on the board
unnamed: R3.P$1, SW3.1
unnamed: D2.CATHODE, R5.P$1
unnamed: D1.CATHODE, R1.P$1
unnamed: C7.P$1, R6.P$2, R7.P$1, R8.P$2, U4.3 (EN)
unnamed: R2.P$2, U2.5 (PROG)
unnamed: R1.P$2, U2.1 (STAT)
unnamed: SW3.2, U3.3 (EN)
unnamed: R4.P$1, SW3.3
USB_N: J1.2 (D-), U1.3; also elsewhere on the board
USB_P: J1.3 (D+), U1.2; also elsewhere on the board
VDD_CORE_EN: R6.P$1; also elsewhere on the board
V_BATT: C1.P$1, D3.A, U2.3 (VBAT), X1.1
V_USB: C2.P$1, C3.P$1, D1.ANODE, D3.C, J1.1 (5V), R3.P$2, U1.4 (VDD/4), U2.4 (VDD), U3.1 (IN); also elsewhere on the board

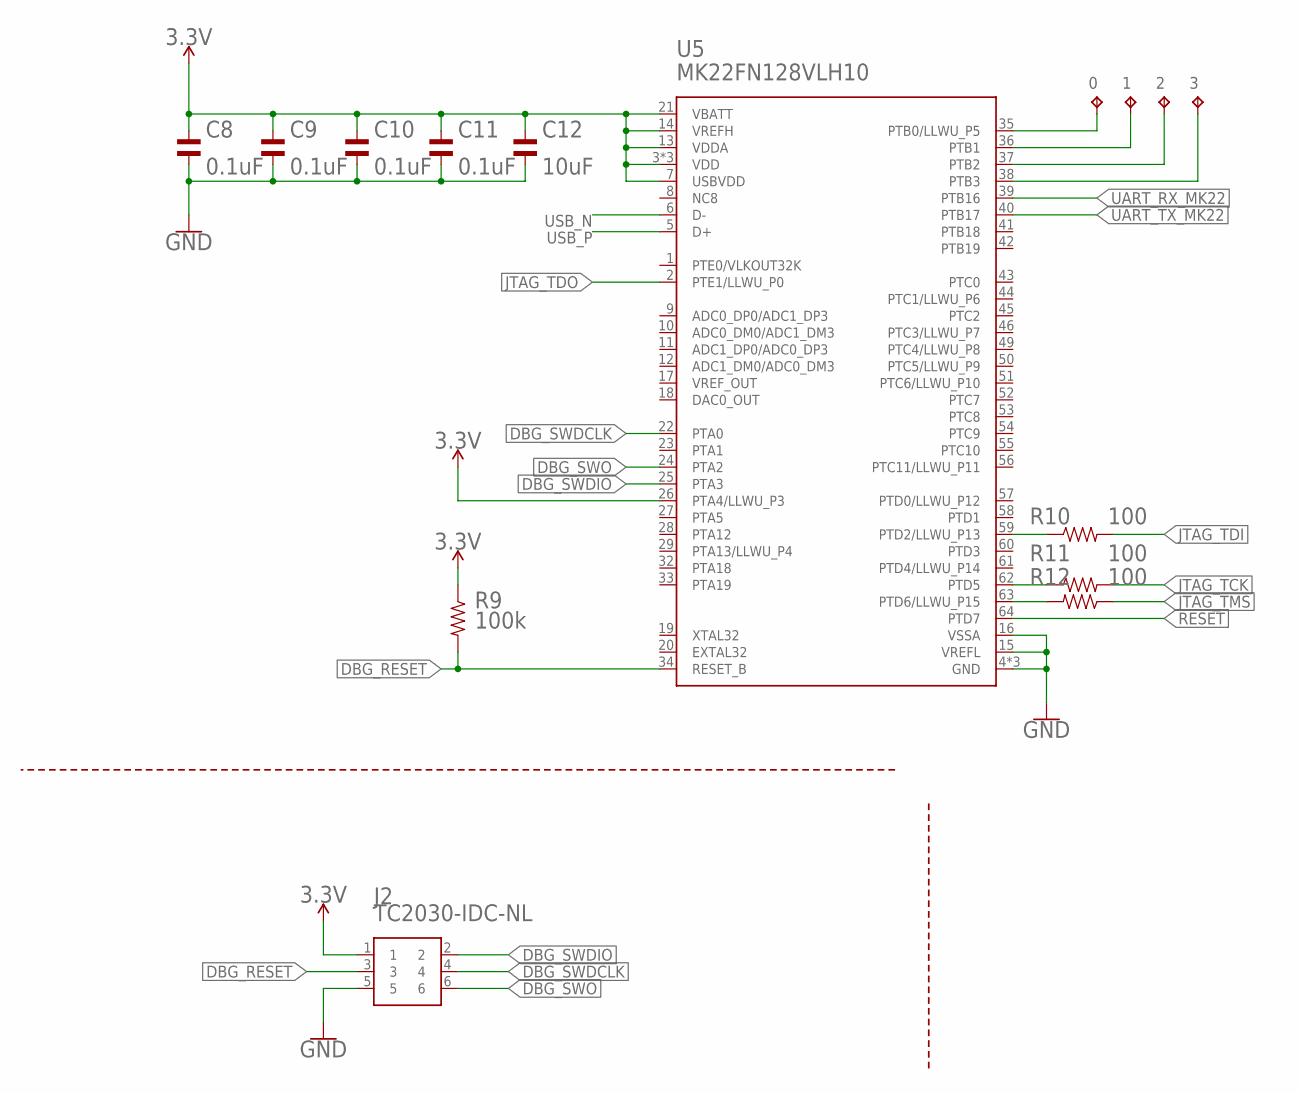
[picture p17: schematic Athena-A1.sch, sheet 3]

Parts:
0, 1, 2, 3: TPB0,65; TP_B0,65
C8, C9, C10, C11: 0.1uF; C0402
C12: 10uF; C0402; MPN CL05A106MP8NUB8
J2: TC2030-IDC-NL; TAG_TC2030-IDC-NL
R9: 100k; R0402
R10, R11, R12: 100; R0402
U5: MK22FN128VLH10; IC_USB_JTAG_LQFP-64

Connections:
3.3V: C8.P$1, C9.P$1, C10.P$1, C11.P$1, C12.P$1, J2.1, R9.P$1, U5.3 (VDD), U5.7 (USBVDD), U5.13 (VDDA), U5.14 (VREFH), U5.21 (VBATT), U5.26 (PTA4/LLWU_P3), U5.30 (VDD), U5.48 (VDD); also elsewhere on the board
DBG_RESET: J2.3, R9.P$2, U5.34 (RESET_B)
DBG_SWDCLK: J2.4, U5.22 (PTA0)
DBG_SWDIO: J2.2, U5.25 (PTA3)
DBG_SWO: J2.6, U5.24 (PTA2)
GND: C8.P$2, C9.P$2, C10.P$2, C11.P$2, C12.P$2, J2.5, U5.4 (GND), U5.15 (VREFL), U5.16 (VSSA), U5.31 (GND), U5.47 (GND); also elsewhere on the board
JTAG_TCK: R11.P$2; also elsewhere on the board
JTAG_TDI: R10.P$2; also elsewhere on the board
JTAG_TDO: U5.2 (PTE1/LLWU_P0); also elsewhere on the board
JTAG_TMS: R12.P$1; also elsewhere on the board
unnamed: R12.P$2, U5.63 (PTD6/LLWU_P15)
unnamed: R11.P$1, U5.62 (PTD5)
unnamed: R10.P$1, U5.59 (PTD2/LLWU_P13)
unnamed: 0.TP, U5.35 (PTB0/LLWU_P5)
unnamed: 1.TP, U5.36 (PTB1)
unnamed: 2.TP, U5.37 (PTB2)
unnamed: 3.TP, U5.38 (PTB3)
RESET: U5.64 (PTD7); also elsewhere on the board
UART_RX_MK22: U5.39 (PTB16); also elsewhere on the board
UART_TX_MK22: U5.40 (PTB17); also elsewhere on the board
USB_N: U5.6 (D-); also elsewhere on the board
USB_P: U5.5 (D+); also elsewhere on the board

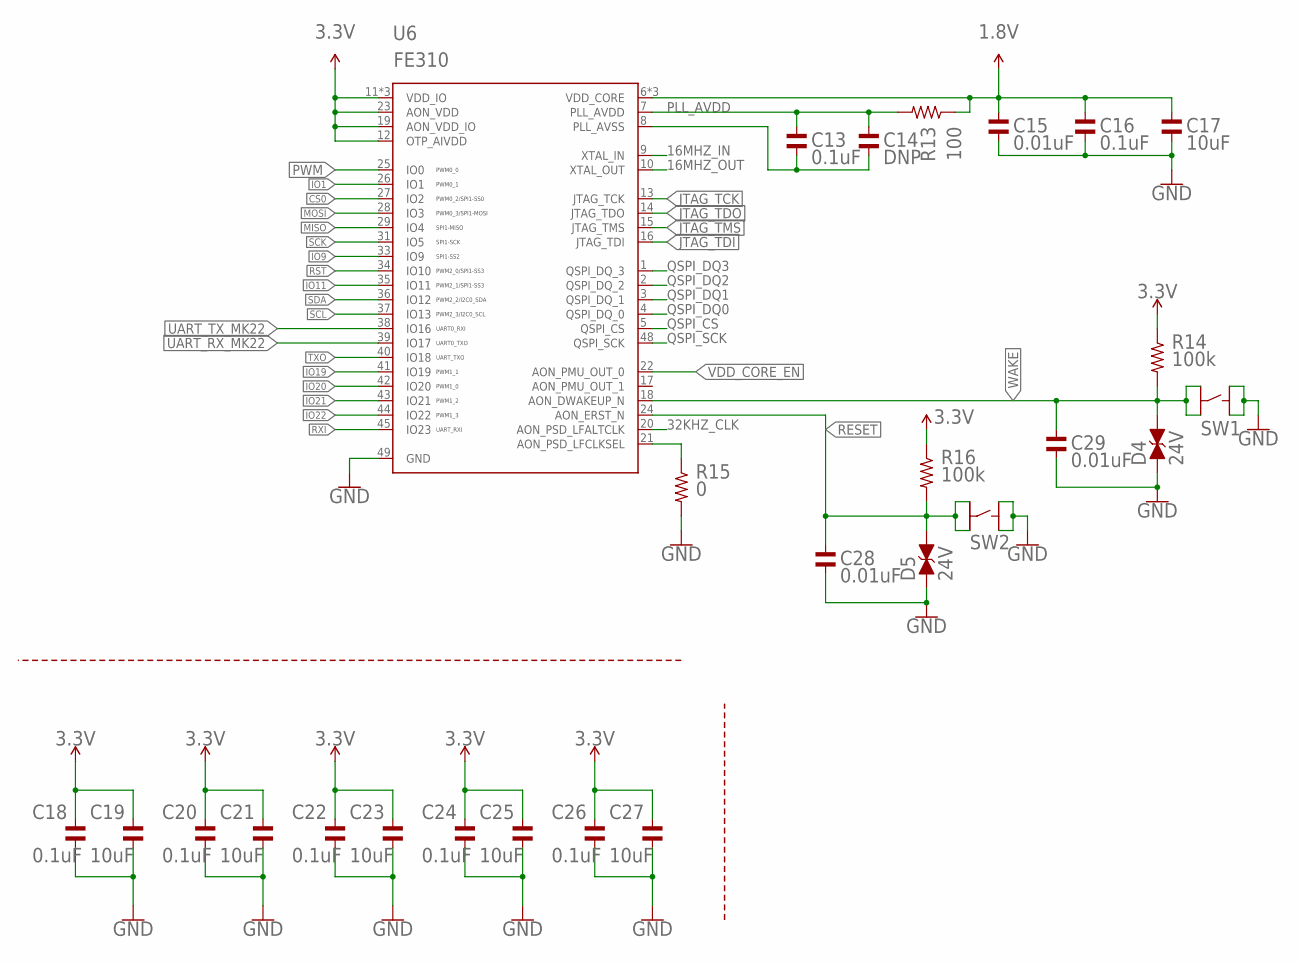
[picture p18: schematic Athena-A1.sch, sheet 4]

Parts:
C13, C16, C18, C20, C22, C24, C26: 0.1uF; C0402
C14: DNP; C0402
C15, C28, C29: 0.01uF; C0402
C17, C19, C21, C23, C25, C27: 10uF; C0402; MPN CL05A106MP8NUB8
D4, D5: 24V; TVS0603
R13: 100; R0402
R14, R16: 100k; R0402
R15: 0; R0402
SW1, SW2: MF-SW-TACT-6MM; TACT4.2MM
U6: FE310; MCU_QFN-48-.4MMPITCH

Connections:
1.8V: C15.P$1, C16.P$1, C17.P$1, R13.P$1, U6.6 (VDD_CORE), U6.30 (VDD_CORE), U6.46 (VDD_CORE); also elsewhere on the board
3.3V: C18.P$1, C19.P$1, C20.P$1, C21.P$1, C22.P$1, C23.P$1, C24.P$1, C25.P$1, C26.P$1, C27.P$1, R14.P$1, R16.P$1, U6.11 (VDD_IO), U6.12 (OTP_AIVDD), U6.19 (AON_VDD_IO), U6.23 (AON_VDD), U6.32 (VDD_IO), U6.47 (VDD_IO); also elsewhere on the board
16MHZ_IN: U6.9 (XTAL_IN); also elsewhere on the board
16MHZ_OUT: U6.10 (XTAL_OUT); also elsewhere on the board
32KHZ_CLK: U6.20 (AON_PSD_LFALTCLK); also elsewhere on the board
CS0: U6.27 (IO2); also elsewhere on the board
GND: C15.P$2, C16.P$2, C17.P$2, C18.P$2, C19.P$2, C20.P$2, C21.P$2, C22.P$2, C23.P$2, C24.P$2, C25.P$2, C26.P$2, C27.P$2, C28.P$2, C29.P$2, D4.1 (A), D5.1 (A), R15.P$2, SW1.P$1, SW1.P$2, SW2.P$1, SW2.P$2, U6.49 (GND); also elsewhere on the board
IO1: U6.26 (IO1); also elsewhere on the board
IO9: U6.33 (IO9); also elsewhere on the board
IO11: U6.35 (IO11); also elsewhere on the board
IO19: U6.41 (IO19); also elsewhere on the board
IO20: U6.42 (IO20); also elsewhere on the board
IO21: U6.43 (IO21); also elsewhere on the board
IO22: U6.44 (IO22); also elsewhere on the board
JTAG_TCK: U6.13 (JTAG_TCK); also elsewhere on the board
JTAG_TDI: U6.16 (JTAG_TDI); also elsewhere on the board
JTAG_TDO: U6.14 (JTAG_TDO); also elsewhere on the board
JTAG_TMS: U6.15 (JTAG_TMS); also elsewhere on the board
MISO: U6.29 (IO4); also elsewhere on the board
MOSI: U6.28 (IO3); also elsewhere on the board
unnamed: R15.P$1, U6.21 (AON_PSD_LFCLKSEL)
unnamed: C13.P$2, C14.P$2, U6.8 (PLL_AVSS)
PLL_AVDD: C13.P$1, C14.P$1, R13.P$2, U6.7 (PLL_AVDD)
PWM: U6.25 (IO0); also elsewhere on the board
QSPI_CS: U6.5 (QSPI_CS); also elsewhere on the board
QSPI_DQ0: U6.4 (QSPI_DQ_0); also elsewhere on the board
QSPI_DQ1: U6.3 (QSPI_DQ_1); also elsewhere on the board
QSPI_DQ2: U6.2 (QSPI_DQ_2); also elsewhere on the board
QSPI_DQ3: U6.1 (QSPI_DQ_3); also elsewhere on the board
QSPI_SCK: U6.48 (QSPI_SCK); also elsewhere on the board
RESET: C28.P$1, D5.2 (C), R16.P$2, SW2.P$3, SW2.P$4, U6.24 (AON_ERST_N); also elsewhere on the board
RST: U6.34 (IO10); also elsewhere on the board
RXI: U6.45 (IO23); also elsewhere on the board
SCK: U6.31 (IO5); also elsewhere on the board
SCL: U6.37 (IO13); also elsewhere on the board
SDA: U6.36 (IO12); also elsewhere on the board
TXO: U6.40 (IO18); also elsewhere on the board
UART_RX_MK22: U6.39 (IO17); also elsewhere on the board
UART_TX_MK22: U6.38 (IO16); also elsewhere on the board
VDD_CORE_EN: U6.22 (AON_PMU_OUT_0); also elsewhere on the board
WAKE: C29.P$1, D4.2 (C), R14.P$2, SW1.P$3, SW1.P$4, U6.18 (AON_DWAKEUP_N)

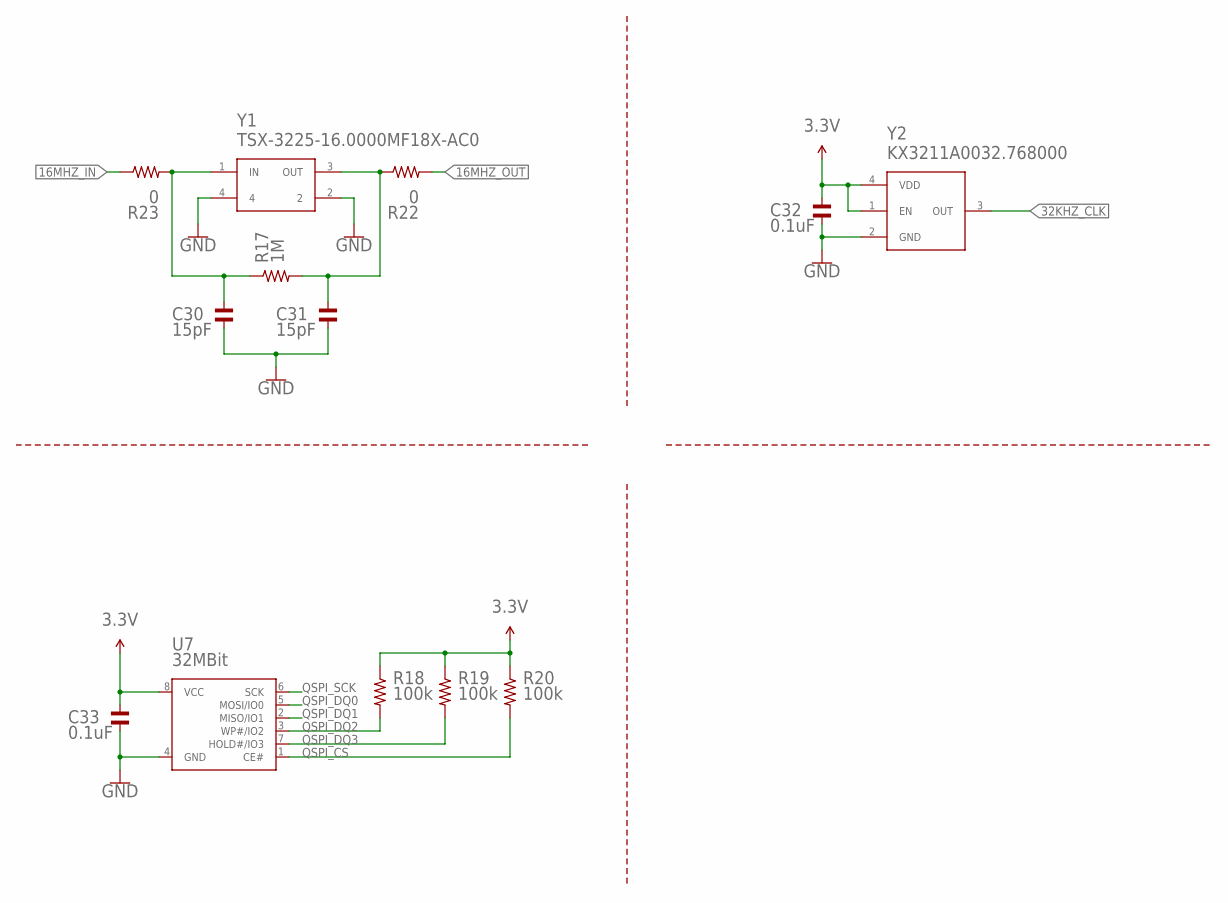
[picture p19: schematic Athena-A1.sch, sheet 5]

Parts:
C30, C31: 15pF; C0402; MPN CL05C150JB5NNNC
C32, C33: 0.1uF; C0402
R17: 1M; R0402
R18, R19, R20: 100k; R0402
R22, R23: 0; R0402
U7: 32MBit; IC-MEMORY_SO08
Y1: TSX-3225-16.0000MF18X-AC0; SMD-4
Y2: KX3211A0032.768000; SMD-4

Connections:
3.3V: C32.P$1, C33.P$1, R18.P$1, R19.P$1, R20.P$1, U7.8 (VCC), Y2.1 (EN), Y2.4 (VDD); also elsewhere on the board
16MHZ_IN: R23.P$1; also elsewhere on the board
16MHZ_OUT: R22.P$2; also elsewhere on the board
32KHZ_CLK: Y2.3 (OUT); also elsewhere on the board
GND: C30.P$2, C31.P$2, C32.P$2, C33.P$2, U7.4 (GND), Y1.2, Y1.4, Y2.2 (GND); also elsewhere on the board
unnamed: C30.P$1, R17.P$1, R23.P$2, Y1.1 (IN)
unnamed: C31.P$1, R17.P$2, R22.P$1, Y1.3 (OUT)
QSPI_CS: R20.P$2, U7.1 (CE#); also elsewhere on the board
QSPI_DQ0: U7.5 (MOSI/IO0); also elsewhere on the board
QSPI_DQ1: U7.2 (MISO/IO1); also elsewhere on the board
QSPI_DQ2: R18.P$2, U7.3 (WP#/IO2); also elsewhere on the board
QSPI_DQ3: R19.P$2, U7.7 (HOLD#/IO3); also elsewhere on the board
QSPI_SCK: U7.6 (SCK); also elsewhere on the board

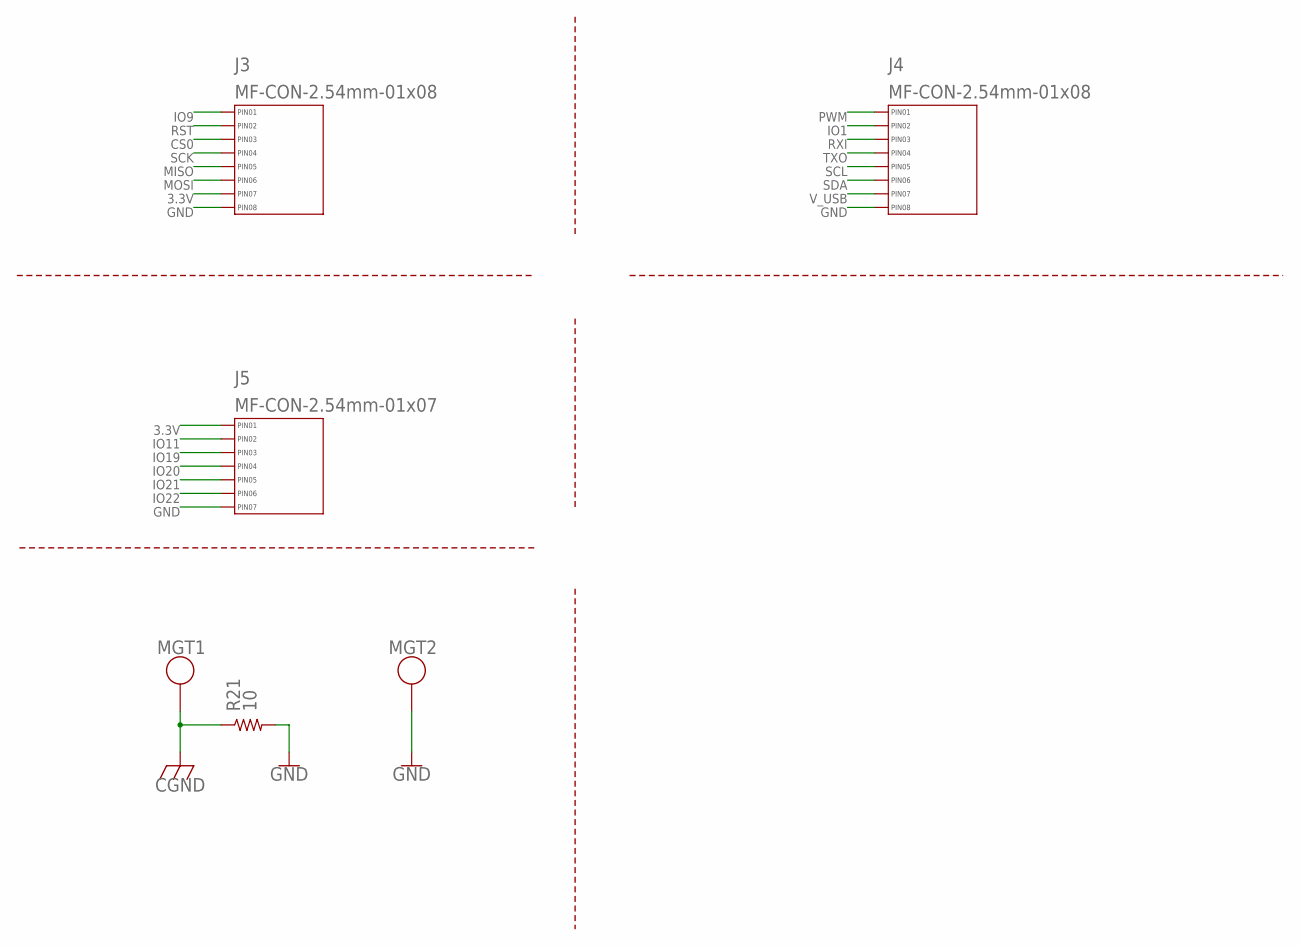
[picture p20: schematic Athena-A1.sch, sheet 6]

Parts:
J3, J4: MF-CON-2.54mm-01x08; PTH_2.54MM_01X08
J5: MF-CON-2.54mm-01x07; PTH_2.54MM_01X07
MGT1, MGT2: MOUNTING_HOLE
R21: 10; R0402

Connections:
3.3V: J3.P$7 (PIN7), J5.P$1 (PIN1); also elsewhere on the board
CGND: MGT1.P$1, R21.P$1; also elsewhere on the board
CS0: J3.P$3 (PIN3); also elsewhere on the board
GND: J3.P$8 (PIN8), J4.P$8 (PIN8), J5.P$7 (PIN7), MGT2.P$1, R21.P$2; also elsewhere on the board
IO1: J4.P$2 (PIN2); also elsewhere on the board
IO9: J3.P$1 (PIN1); also elsewhere on the board
IO11: J5.P$2 (PIN2); also elsewhere on the board
IO19: J5.P$3 (PIN3); also elsewhere on the board
IO20: J5.P$4 (PIN4); also elsewhere on the board
IO21: J5.P$5 (PIN5); also elsewhere on the board
IO22: J5.P$6 (PIN6); also elsewhere on the board
MISO: J3.P$5 (PIN5); also elsewhere on the board
MOSI: J3.P$6 (PIN6); also elsewhere on the board
PWM: J4.P$1 (PIN1); also elsewhere on the board
RST: J3.P$2 (PIN2); also elsewhere on the board
RXI: J4.P$3 (PIN3); also elsewhere on the board
SCK: J3.P$4 (PIN4); also elsewhere on the board
SCL: J4.P$5 (PIN5); also elsewhere on the board
SDA: J4.P$6 (PIN6); also elsewhere on the board
TXO: J4.P$4 (PIN4); also elsewhere on the board
V_USB: J4.P$7 (PIN7); also elsewhere on the board

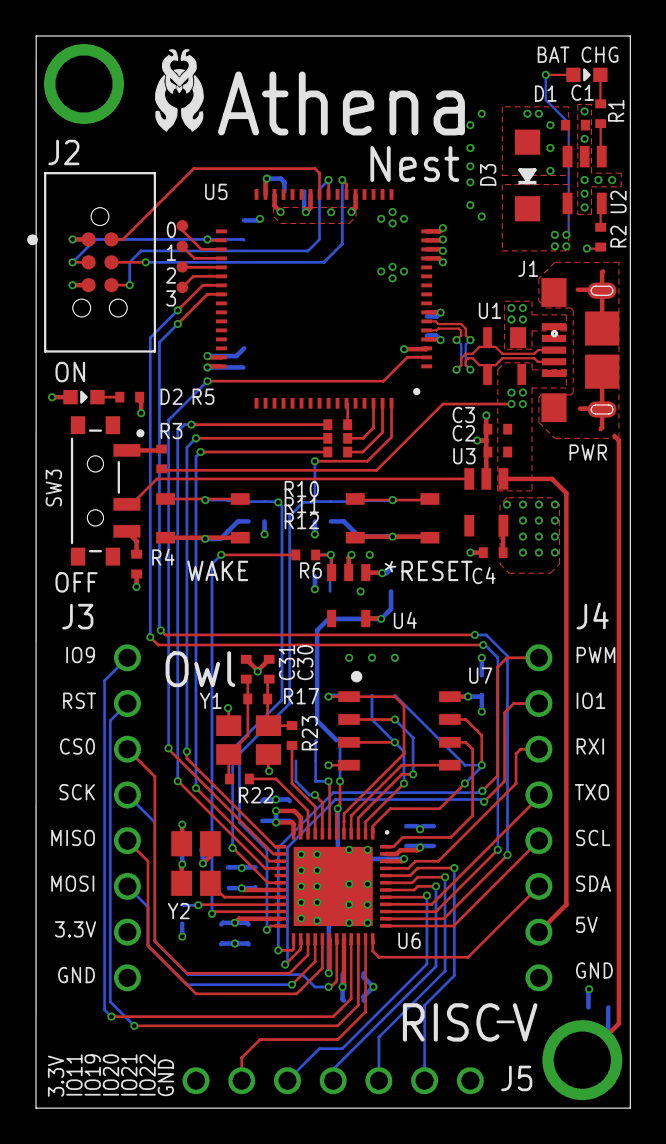
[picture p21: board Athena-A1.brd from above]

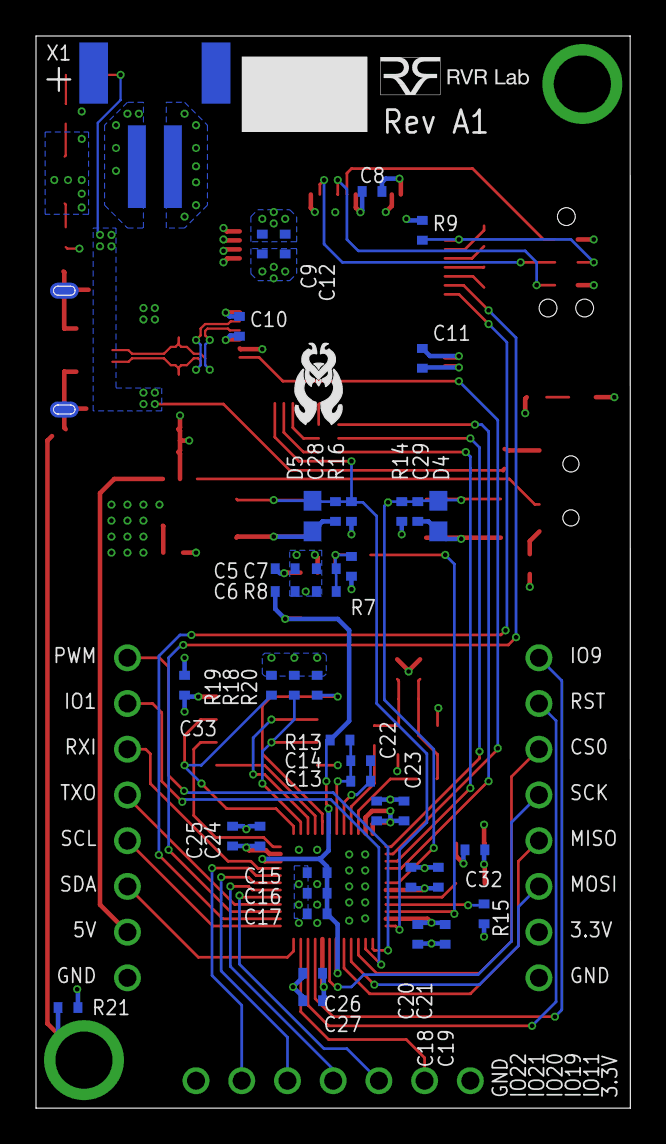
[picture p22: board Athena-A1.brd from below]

Board: 4 copper layers, 33.0 x 59.6 mm, 85 parts (41 on the bottom side), 67 nets.

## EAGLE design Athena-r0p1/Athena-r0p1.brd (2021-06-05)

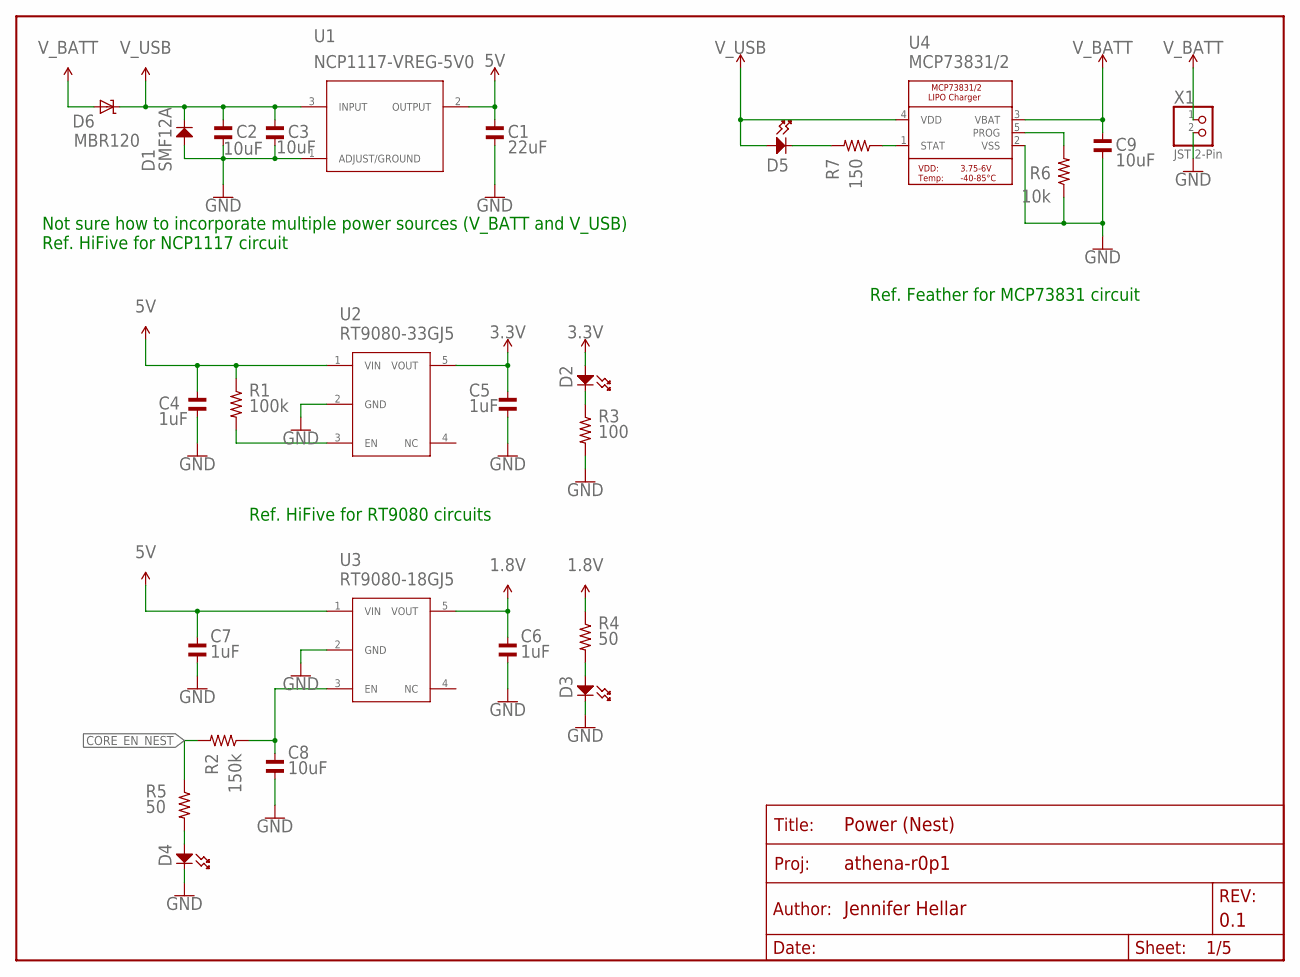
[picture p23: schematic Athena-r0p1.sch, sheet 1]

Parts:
C1: 22uF; C0603
C2, C3, C8, C9: 10uF; C0603
C4, C5, C6, C7: 1uF; C0603
D1: SMF12A; SMFSERIES_LTF
D2, D3, D4: MF-LED-0603-GREEN; LED0603
D5: MF-LED-0603-RED; LED0603
D6: MBR120; SOD-123
FRAME1: FRAME-LETTER; SPARKFUN-AESTHETICS_CREATIVE_COMMONS
R1: 100k; R0603
R2: 150k; R0603
R3: 100; R0603
R4, R5: 50; R0603
R6: 10k; R0603
R7: 150; R0603
U1: NCP1117-VREG-5V0; SOT223-3_ONS
U2: RT9080-33GJ5; TSOT23-5_ONS
U3: RT9080-18GJ5; TSOT23-5_ONS
U4: MCP73831/2; SOT23-5
X1: JST 2-Pin; JSTPH2

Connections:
1.8V: C6.P$1, R4.P$1, U3.5 (VOUT); also elsewhere on the board
3.3V: C5.P$1, D2.ANODE, U2.5 (VOUT); also elsewhere on the board
5V: C1.P$1, C4.P$1, C7.P$1, R1.P$1, U1.2 (OUTPUT), U2.1 (VIN), U3.1 (VIN); also elsewhere on the board
CORE_EN_NEST: R2.P$2, R5.P$1; also elsewhere on the board
GND: C1.P$2, C2.P$2, C3.P$2, C4.P$2, C5.P$2, C6.P$2, C7.P$2, C8.P$2, C9.P$2, D1.2 (ANODE), D3.CATHODE, D4.CATHODE, R3.P$2, R6.P$1, U1.1 (ADJUST/GROUND), U2.2 (GND), U3.2 (GND), U4.2 (VSS), X1.2; also elsewhere on the board
unnamed: D3.ANODE, R4.P$2
unnamed: D2.CATHODE, R3.P$1
unnamed: R1.P$2, U2.3 (EN)
unnamed: C8.P$1, R2.P$1, U3.3 (EN)
unnamed: D4.ANODE, R5.P$2
unnamed: R7.P$1, U4.1 (STAT)
unnamed: R6.P$2, U4.5 (PROG)
unnamed: D5.CATHODE, R7.P$2
V_BATT: C9.P$1, D6.A, U4.3 (VBAT), X1.1
V_USB: C2.P$1, C3.P$1, D1.1 (CATHODE), D5.ANODE, D6.C, U1.3 (INPUT), U4.4 (VDD); also elsewhere on the board

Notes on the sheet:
Not sure how to incorporate multiple power sources (V_BATT and V_USB) Ref. HiFive for NCP1117 circuit
Ref. HiFive for RT9080 circuits
Ref. Feather for MCP73831 circuit

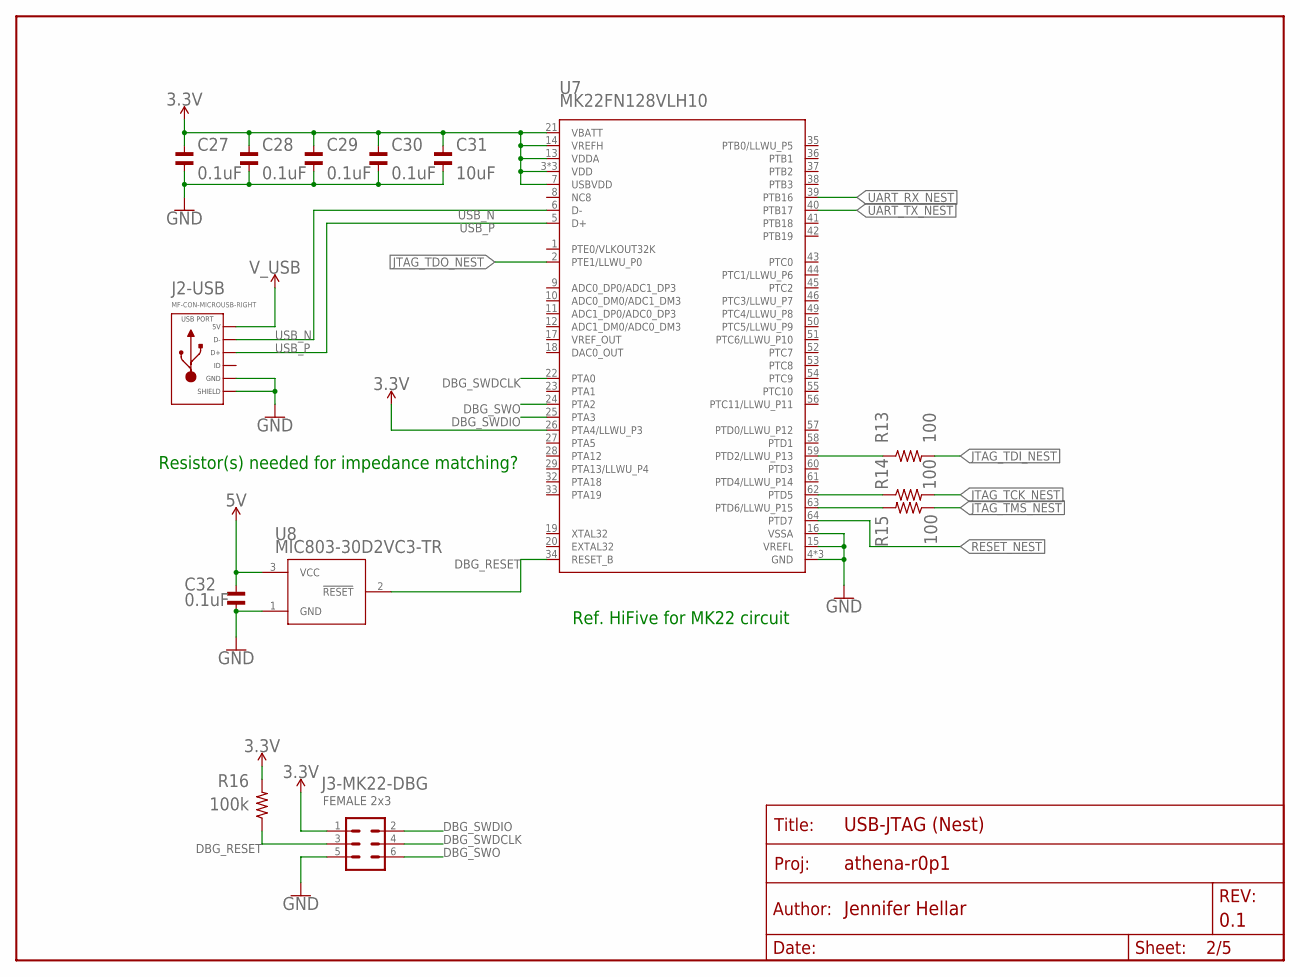
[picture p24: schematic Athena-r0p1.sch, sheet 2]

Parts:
C27, C28, C29, C30, C32: 0.1uF; C0603
C31: 10uF; C0603
FRAME3: FRAME-LETTER; SPARKFUN-AESTHETICS_CREATIVE_COMMONS
J2-USB: MF-CON-MICROUSB-RIGHT; MICROUSB-RIGHT
J3-MK22-DBG: FEMALE 2x3; 2X3
R13, R14, R15: 100; R0603
R16: 100k; R0603
U7: MK22FN128VLH10; IC_USB_JTAG_LQFP-64
U8: MIC803-30D2VC3-TR; SC-70_C3_MCH

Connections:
3.3V: C27.P$1, C28.P$1, C29.P$1, C30.P$1, C31.P$1, J3-MK22-DBG.1, R16.P$2, U7.3 (VDD), U7.7 (USBVDD), U7.13 (VDDA), U7.14 (VREFH), U7.21 (VBATT), U7.26 (PTA4/LLWU_P3), U7.30 (VDD), U7.48 (VDD); also elsewhere on the board
5V: C32.P$1, U8.3 (VCC); also elsewhere on the board
DBG_RESET: J3-MK22-DBG.3, R16.P$1, U7.34 (RESET_B), U8.2 (!RESET)
DBG_SWDCLK: J3-MK22-DBG.4, U7.22 (PTA0)
DBG_SWDIO: J3-MK22-DBG.2, U7.25 (PTA3)
DBG_SWO: J3-MK22-DBG.6, U7.24 (PTA2)
GND: C27.P$2, C28.P$2, C29.P$2, C30.P$2, C31.P$2, C32.P$2, J2-USB.5 (GND), J2-USB.S1 (SLD), J2-USB.S2 (SLD), J2-USB.S3 (SLD), J2-USB.S4 (SLD), J2-USB.S5 (SLD), J2-USB.S6 (SLD), J3-MK22-DBG.5, U7.4 (GND), U7.15 (VREFL), U7.16 (VSSA), U7.31 (GND), U7.47 (GND), U8.1 (GND); also elsewhere on the board
JTAG_TCK_NEST: R14.P$2; also elsewhere on the board
JTAG_TDI_NEST: R13.P$2; also elsewhere on the board
JTAG_TDO_NEST: U7.2 (PTE1/LLWU_P0); also elsewhere on the board
JTAG_TMS_NEST: R15.P$1; also elsewhere on the board
unnamed: R13.P$1, U7.59 (PTD2/LLWU_P13)
unnamed: R14.P$1, U7.62 (PTD5)
unnamed: R15.P$2, U7.63 (PTD6/LLWU_P15)
RESET_NEST: U7.64 (PTD7); also elsewhere on the board
UART_RX_NEST: U7.39 (PTB16); also elsewhere on the board
UART_TX_NEST: U7.40 (PTB17); also elsewhere on the board
USB_N: J2-USB.2 (D-), U7.6 (D-)
USB_P: J2-USB.3 (D+), U7.5 (D+)
V_USB: J2-USB.1 (5V); also elsewhere on the board

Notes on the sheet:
Resistor(s) needed for impedance matching?
Ref. HiFive for MK22 circuit

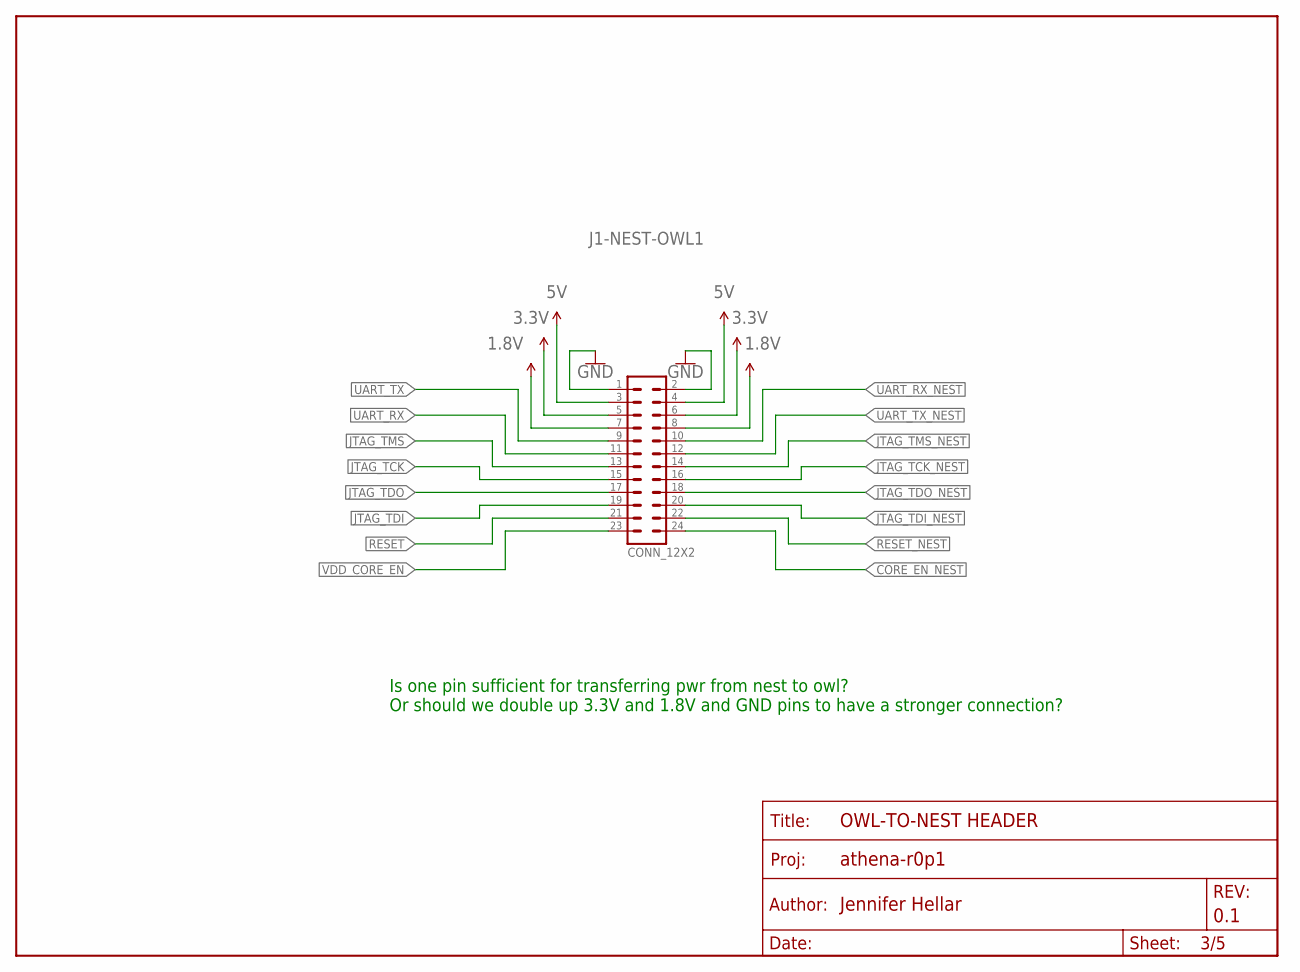
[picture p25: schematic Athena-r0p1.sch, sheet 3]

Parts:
FRAME5: FRAME-LETTER; SPARKFUN-AESTHETICS_CREATIVE_COMMONS
J1-NEST-OWL1: CONN_12X2; 2X12

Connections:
1.8V: J1-NEST-OWL1.7, J1-NEST-OWL1.8; also elsewhere on the board
3.3V: J1-NEST-OWL1.5, J1-NEST-OWL1.6; also elsewhere on the board
5V: J1-NEST-OWL1.3, J1-NEST-OWL1.4; also elsewhere on the board
CORE_EN_NEST: J1-NEST-OWL1.24; also elsewhere on the board
GND: J1-NEST-OWL1.1, J1-NEST-OWL1.2; also elsewhere on the board
JTAG_TCK: J1-NEST-OWL1.15; also elsewhere on the board
JTAG_TCK_NEST: J1-NEST-OWL1.16; also elsewhere on the board
JTAG_TDI: J1-NEST-OWL1.19; also elsewhere on the board
JTAG_TDI_NEST: J1-NEST-OWL1.20; also elsewhere on the board
JTAG_TDO: J1-NEST-OWL1.17; also elsewhere on the board
JTAG_TDO_NEST: J1-NEST-OWL1.18; also elsewhere on the board
JTAG_TMS: J1-NEST-OWL1.13; also elsewhere on the board
JTAG_TMS_NEST: J1-NEST-OWL1.14; also elsewhere on the board
RESET: J1-NEST-OWL1.21; also elsewhere on the board
RESET_NEST: J1-NEST-OWL1.22; also elsewhere on the board
UART_RX: J1-NEST-OWL1.11; also elsewhere on the board
UART_RX_NEST: J1-NEST-OWL1.10; also elsewhere on the board
UART_TX: J1-NEST-OWL1.9; also elsewhere on the board
UART_TX_NEST: J1-NEST-OWL1.12; also elsewhere on the board
VDD_CORE_EN: J1-NEST-OWL1.23; also elsewhere on the board

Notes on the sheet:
Is one pin sufficient for transferring pwr from nest to owl? Or should we double up 3.3V and 1.8V and GND pins to have a stronger connection?

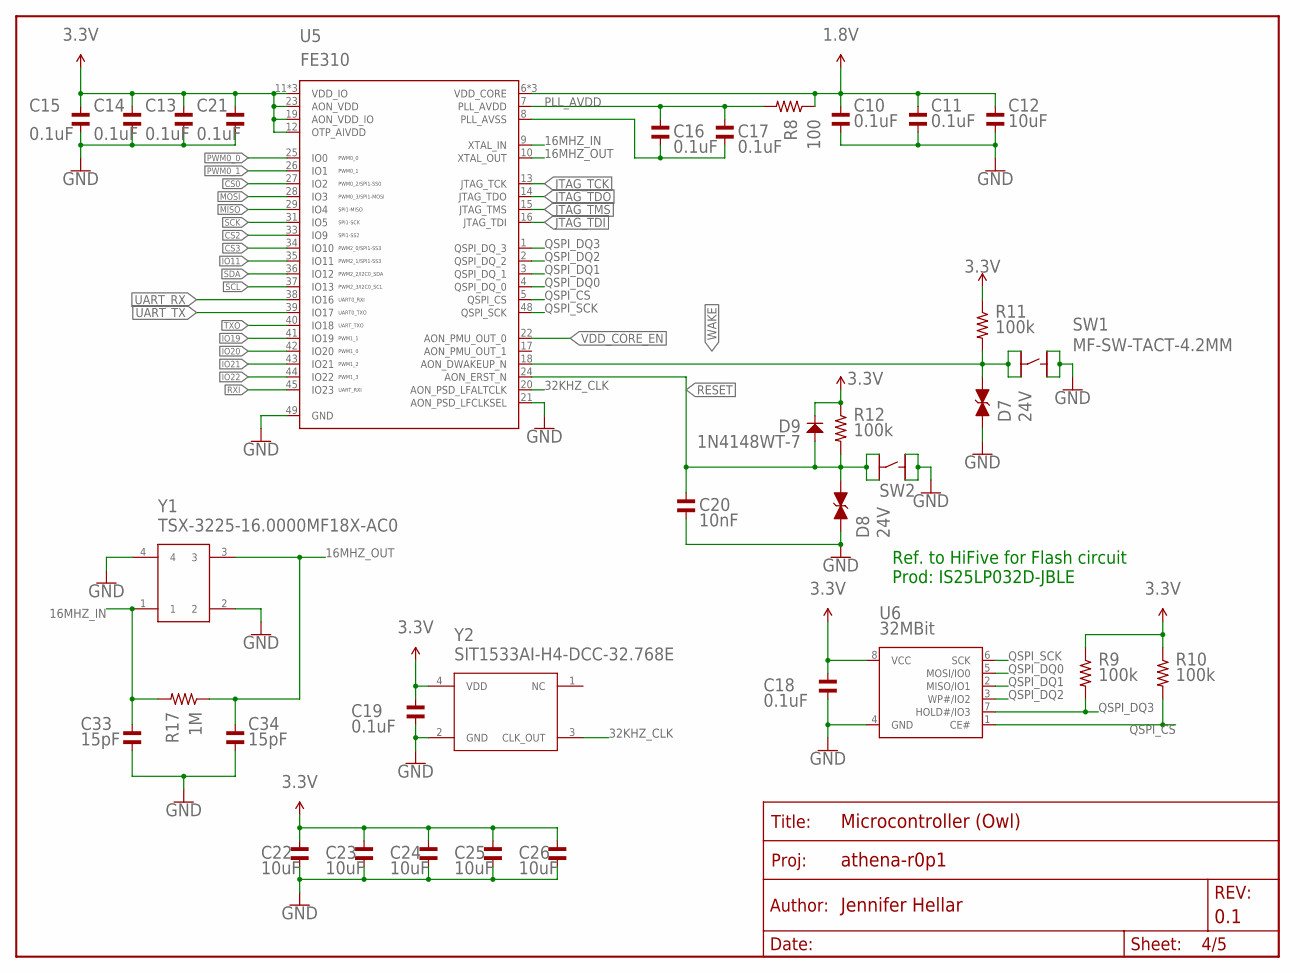
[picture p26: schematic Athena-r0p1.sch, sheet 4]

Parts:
C10, C11, C13, C14, C15, C16, C17, C18, C19, C21: 0.1uF; C0603
C12, C22, C23, C24, C25, C26: 10uF; C0603
C20: 10nF; C0603
C33, C34: 15pF; C0603
D7, D8: 24V; SPARKFUN-DISCRETESEMI_0603
D9: 1N4148WT-7; SOD-523
FRAME2: FRAME-LETTER; SPARKFUN-AESTHETICS_CREATIVE_COMMONS
R8: 100; R0603
R9, R10, R11, R12: 100k; R0603
R17: 1M; R0603
SW1, SW2: MF-SW-TACT-4.2MM; TACT4.2MM
U5: FE310; MCU_QFN-48-.4MMPITCH
U6: 32MBit; IC-MEMORY_SO08
Y1: TSX-3225-16.0000MF18X-AC0; TSX-3225
Y2: SIT1533AI-H4-DCC-32.768E; XTAL4_SIT1533_SIT

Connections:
1.8V: C10.P$1, C11.P$1, C12.P$1, R8.P$1, U5.6 (VDD_CORE), U5.30 (VDD_CORE), U5.46 (VDD_CORE); also elsewhere on the board
3.3V: C13.P$1, C14.P$1, C15.P$1, C18.P$1, C19.P$1, C21.P$1, C22.P$1, C23.P$1, C24.P$1, C25.P$1, C26.P$1, D9.K (CATHODE), R9.P$1, R10.P$1, R11.P$1, R12.P$1, U5.11 (VDD_IO), U5.12 (OTP_AIVDD), U5.19 (AON_VDD_IO), U5.23 (AON_VDD), U5.32 (VDD_IO), U5.47 (VDD_IO), U6.8 (VCC), Y2.4 (VDD); also elsewhere on the board
16MHZ_IN: C33.P$1, R17.P$2, U5.9 (XTAL_IN), Y1.1
16MHZ_OUT: C34.P$1, R17.P$1, U5.10 (XTAL_OUT), Y1.3
32KHZ_CLK: U5.20 (AON_PSD_LFALTCLK), Y2.3 (CLK_OUT)
CS0: U5.27 (IO2); also elsewhere on the board
CS2: U5.33 (IO9); also elsewhere on the board
CS3: U5.34 (IO10); also elsewhere on the board
GND: C10.P$2, C11.P$2, C12.P$2, C13.P$2, C14.P$2, C15.P$2, C18.P$2, C19.P$2, C20.P$2, C21.P$2, C22.P$2, C23.P$2, C24.P$2, C25.P$2, C26.P$2, C33.P$2, C34.P$2, D7.1 (A), D8.1 (A), SW1.P$1, SW1.P$2, SW2.P$1, SW2.P$2, U5.21 (AON_PSD_LFCLKSEL), U5.49 (GND), U6.4 (GND), Y1.2, Y1.4, Y2.2 (GND); also elsewhere on the board
IO11: U5.35 (IO11); also elsewhere on the board
IO19: U5.41 (IO19); also elsewhere on the board
IO20: U5.42 (IO20); also elsewhere on the board
IO21: U5.43 (IO21); also elsewhere on the board
IO22: U5.44 (IO22); also elsewhere on the board
JTAG_TCK: U5.13 (JTAG_TCK); also elsewhere on the board
JTAG_TDI: U5.16 (JTAG_TDI); also elsewhere on the board
JTAG_TDO: U5.14 (JTAG_TDO); also elsewhere on the board
JTAG_TMS: U5.15 (JTAG_TMS); also elsewhere on the board
MISO: U5.29 (IO4); also elsewhere on the board
MOSI: U5.28 (IO3); also elsewhere on the board
unnamed: C16.P$2, C17.P$2, U5.8 (PLL_AVSS)
PLL_AVDD: C16.P$1, C17.P$1, R8.P$2, U5.7 (PLL_AVDD)
PWM0_0: U5.25 (IO0); also elsewhere on the board
PWM0_1: U5.26 (IO1); also elsewhere on the board
QSPI_CS: R10.P$2, U5.5 (QSPI_CS), U6.1 (CE#)
QSPI_DQ0: U5.4 (QSPI_DQ_0), U6.5 (MOSI/IO0)
QSPI_DQ1: U5.3 (QSPI_DQ_1), U6.2 (MISO/IO1)
QSPI_DQ2: U5.2 (QSPI_DQ_2), U6.3 (WP#/IO2)
QSPI_DQ3: R9.P$2, U5.1 (QSPI_DQ_3), U6.7 (HOLD#/IO3)
QSPI_SCK: U5.48 (QSPI_SCK), U6.6 (SCK)
RESET: C20.P$1, D8.2 (C), D9.A (ANODE), R12.P$2, SW2.P$3, SW2.P$4, U5.24 (AON_ERST_N); also elsewhere on the board
RXI: U5.45 (IO23); also elsewhere on the board
SCK: U5.31 (IO5); also elsewhere on the board
SCL: U5.37 (IO13); also elsewhere on the board
SDA: U5.36 (IO12); also elsewhere on the board
TXO: U5.40 (IO18); also elsewhere on the board
UART_RX: U5.38 (IO16); also elsewhere on the board
UART_TX: U5.39 (IO17); also elsewhere on the board
VDD_CORE_EN: U5.22 (AON_PMU_OUT_0); also elsewhere on the board
WAKE: D7.2 (C), R11.P$2, SW1.P$3, SW1.P$4, U5.18 (AON_DWAKEUP_N); also elsewhere on the board

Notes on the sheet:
Ref. to HiFive for Flash circuit Prod: IS25LP032D-JBLE

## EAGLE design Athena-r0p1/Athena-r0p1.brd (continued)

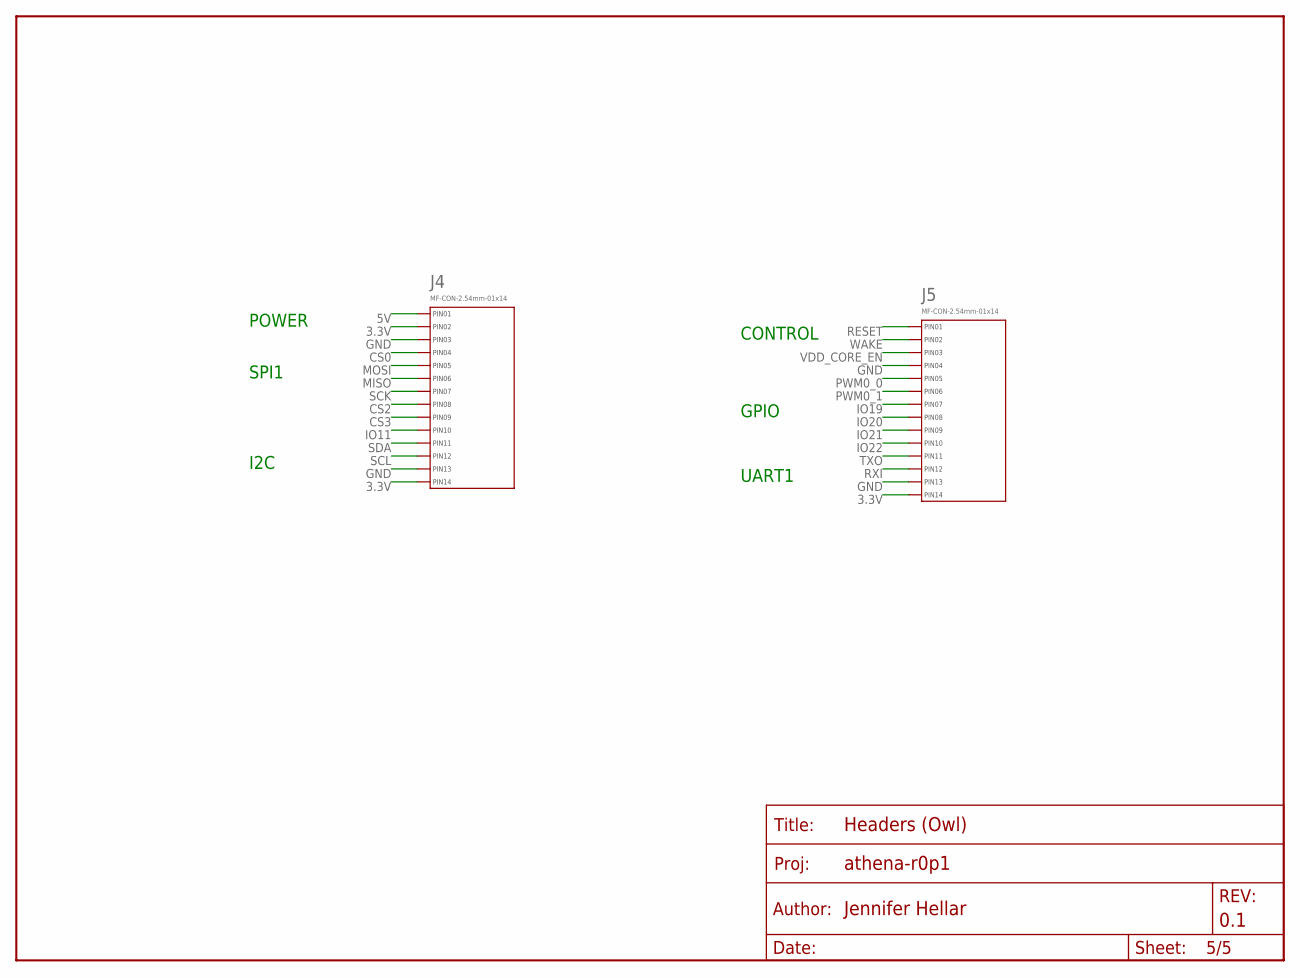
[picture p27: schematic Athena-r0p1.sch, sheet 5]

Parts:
FRAME4: FRAME-LETTER; SPARKFUN-AESTHETICS_CREATIVE_COMMONS
J4, J5: MF-CON-2.54mm-01x14; PTH_2.54MM_01X14

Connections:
3.3V: J4.P$2 (PIN2), J4.P$14 (PIN14), J5.P$14 (PIN14); also elsewhere on the board
5V: J4.P$1 (PIN1); also elsewhere on the board
CS0: J4.P$4 (PIN4); also elsewhere on the board
CS2: J4.P$8 (PIN8); also elsewhere on the board
CS3: J4.P$9 (PIN9); also elsewhere on the board
GND: J4.P$3 (PIN3), J4.P$13 (PIN13), J5.P$4 (PIN4), J5.P$13 (PIN13); also elsewhere on the board
IO11: J4.P$10 (PIN10); also elsewhere on the board
IO19: J5.P$7 (PIN7); also elsewhere on the board
IO20: J5.P$8 (PIN8); also elsewhere on the board
IO21: J5.P$9 (PIN9); also elsewhere on the board
IO22: J5.P$10 (PIN10); also elsewhere on the board
MISO: J4.P$6 (PIN6); also elsewhere on the board
MOSI: J4.P$5 (PIN5); also elsewhere on the board
PWM0_0: J5.P$5 (PIN5); also elsewhere on the board
PWM0_1: J5.P$6 (PIN6); also elsewhere on the board
RESET: J5.P$1 (PIN1); also elsewhere on the board
RXI: J5.P$12 (PIN12); also elsewhere on the board
SCK: J4.P$7 (PIN7); also elsewhere on the board
SCL: J4.P$12 (PIN12); also elsewhere on the board
SDA: J4.P$11 (PIN11); also elsewhere on the board
TXO: J5.P$11 (PIN11); also elsewhere on the board
VDD_CORE_EN: J5.P$3 (PIN3); also elsewhere on the board
WAKE: J5.P$2 (PIN2); also elsewhere on the board

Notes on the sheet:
SPI1
I2C
UART1
GPIO
CONTROL
POWER

Board: 4 copper layers, 78 parts (0 on the bottom side), 68 nets, no tracks yet.

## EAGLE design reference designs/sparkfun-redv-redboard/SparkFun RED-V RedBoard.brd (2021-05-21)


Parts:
C1: 10uF; 0603
C3, C15: 10uF; EIA3216
C4, C10, C12, C23, C24, C25, C26: 0.1uF; 0603
C5: 47uF; PANASONIC_D
C9, C16: 1.0uF; 0603
D1: 1A/40V/500mV; SMA-DIODE
D2, D4: 24V; 0603
F1: 6V 0.5A; 0805
FRAME2: FRAME-LETTER; CREATIVE_COMMONS
IC3: LM1117; SOT223-ALT1
J2: USB Female Type C Connector; USB-C-16P
J3: POWER_JACKSUPER_BOMB_DIGITY; POWER_JACK_SMD_OVERPASTE_SUPER_BOMB_DIGITY
JP1: JUMPER-SMT_2_NO_NO-SILK; SMT-JUMPER_2_NO_NO-SILK
JP3, JP4, JP5, JP6: STAND-OFF
JP8, JP9, JP15, JP16: FIDUCIAL1X2; FIDUCIAL-1X2
LED2: RED; LED-1206
LOGO1: SFE_LOGO_NAME_FLAME.1_INCH; SFE_LOGO_NAME_FLAME_.1
Q1: 1.1A/60V/600mΩ; SOT23-3
R2, R4: 10k; 0603
R3, R6, R7: 100k; 0603
R8: 100; 0603
R14: 715; 0603
R15: 240; 0603
R18, R19: 5.1k; 0603
S1, S2: MOMENTARY-SWITCH-SPST-SMD-6.2MM-TALL; TACTILE_SWITCH_SMD_6.2MM_TALL
U2: AP2127K-1.8V; SOT23-5
U3: AP2112-3.3V; SOT23-5
U4: FE310; QFN-48-.4MMPITCH
U$16: OSHW-LOGOS; OSHW-LOGO-S
Y1: 32.768KHZ; CRYSTAL-SMD-2X1.2MM
Y2: 16MHz; RESONATOR-SMD-3.2X1.3

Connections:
1.8V: C1.1, C9.1, C23.1, C24.1, R8.1, U2.5 (OUT), U4.6 (VDD_CORE), U4.30 (VDD_CORE), U4.46 (VDD_CORE)
3.3V: C16.1, R3.2, R6.2, R7.2, U3.5 (OUT), U4.11 (VDD_IO), U4.12 (OTP_AIVDD), U4.19 (AON_VDD_IO), U4.23 (AON_VDD), U4.32 (VDD_IO), U4.47 (VDD_IO), Y1.4 (VCC); also elsewhere on the board
5V: C3.+, C4.1, IC3.2 (OUT), IC3.4 (OUT), Q1.2 (S), R2.2, R4.2, R15.2, U2.1 (IN), U3.1 (IN), U3.3 (EN); also elsewhere on the board
!RESET: D4.2 (C), R6.1, S2.A2 (1), U4.24 (AON_ERST_N); also elsewhere on the board
!WAKE: D2.2 (C), R7.1, S1.A2 (1), U4.18 (AON_DWAKEUP_N); also elsewhere on the board
CORE_ENABLE: U2.3 (EN), U4.22 (AON_PMU_OUT_0)
D+: J2.A6 (D+), J2.B6 (D+); also elsewhere on the board
D-: J2.A7 (D-), J2.B7 (D-); also elsewhere on the board
GND: C1.2, C3.-, C4.2, C5.-, C9.2, C10.2, C12.2, C15.-, C16.2, C23.2, C24.2, D2.1 (A), D4.1 (A), J2.GND, J2.GND2 (GND), J2.SHLD1 (SHLD), J2.SHLD2 (SHLD), J2.SHLD3 (SHLD), J2.SHLD4 (SHLD), J2.SHLD5 (SHLD), J2.SHLD6 (SHLD), J2.SHLD7 (SHLD), J2.SHLD8 (SHLD), J3.GND (GNDBREAK), LED2.C, R14.1, R18.1, R19.1, S1.B2 (2), S2.B2 (2), U2.2 (GND), U3.2 (GND), U4.21 (AON_PSD_LFCLKSEL), U4.49 (GND), Y1.2 (GND), Y2.2; also elsewhere on the board
INSERT: J3.P$4 (GND), Q1.1 (G), R4.1
IO0: U4.25 (IO0); also elsewhere on the board
IO1: U4.26 (IO1); also elsewhere on the board
IO2: U4.27 (IO2); also elsewhere on the board
IO9: U4.33 (IO9); also elsewhere on the board
IO10: U4.34 (IO10); also elsewhere on the board
IO11: U4.35 (IO11); also elsewhere on the board
IO18: U4.40 (IO18); also elsewhere on the board
IO19: U4.41 (IO19); also elsewhere on the board
IO20: U4.42 (IO20); also elsewhere on the board
IO21: U4.43 (IO21); also elsewhere on the board
IO22: U4.44 (IO22); also elsewhere on the board
IO23: U4.45 (IO23); also elsewhere on the board
unnamed: LED2.A, R2.1
unnamed: U4.10 (XTAL_OUT), Y2.1
unnamed: U4.9 (XTAL_IN), Y2.3
unnamed: U4.20 (AON_PSD_LFALTCLK), Y1.3 (OUT)
unnamed: C25.2, C26.2, U4.8 (PLL_AVSS)
unnamed: J2.B5 (CC2), R18.2
unnamed: IC3.1 (ADJ), R14.2, R15.1
unnamed: J2.A5 (CC1), R19.2
PLL_AVDD: C25.1, C26.1, R8.2, U4.7 (PLL_AVDD)
PWRIN: D1.A, J3.VIN0 (PWR)
QSPI_0: U4.4 (QSPI_DQ_0); also elsewhere on the board
QSPI_1: U4.3 (QSPI_DQ_1); also elsewhere on the board
QSPI_2: U4.2 (QSPI_DQ_2); also elsewhere on the board
QSPI_3: U4.1 (QSPI_DQ_3); also elsewhere on the board
QSPI_CS: R3.1, U4.5 (QSPI_CS); also elsewhere on the board
QSPI_SCK: U4.48 (QSPI_SCK); also elsewhere on the board
RXI: U4.38 (IO16); also elsewhere on the board
SCL: U4.37 (IO13); also elsewhere on the board
SDA: U4.36 (IO12); also elsewhere on the board
SPI_MISO: U4.29 (IO4); also elsewhere on the board
SPI_MOSI: U4.28 (IO3); also elsewhere on the board
SPI_SCK: U4.31 (IO5); also elsewhere on the board
TCK: U4.13 (JTAG_TCK); also elsewhere on the board
TDI: U4.16 (JTAG_TDI); also elsewhere on the board
TDO: U4.14 (JTAG_TDO); also elsewhere on the board
TMS: U4.15 (JTAG_TMS); also elsewhere on the board
TXO: U4.39 (IO17); also elsewhere on the board
USBVCC: C12.1, C15.+, F1.2, JP1.2, Q1.3 (D)
VIN: C5.+, D1.C, IC3.3 (IN); also elsewhere on the board
VUSB: C10.1, F1.1, J2.VBUS1 (VBUS), J2.VBUS2 (VBUS), JP1.1

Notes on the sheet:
Power Supply
FE310
USB-C Connector
Based on Arduino by: M.Banzi, D.Cuartielles, T.Igoe, G.Martino, D.Mellis
Andy England
v10
VIN Range: 7-15V
3.3V 600mA Out
450mA Out
Closing this jumper bypasses the .5A fuse. Only close it if you need a lot of current.


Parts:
C2, C14, C17, C18, C19, C20, C21, C22, C27, C28, C29: 0.1uF; 0603
C6, C7, C8, C11, C13, C30: 10uF; 0603
D5: GREEN; LED-1206
FRAME1: FRAME-LETTER; CREATIVE_COMMONS
I2C: JUMPER-SMT_3_NO_NO-SILK; SMT-JUMPER_3_NO_NO-SILK
J4: QWIIC; JST04_1MM_RA
J5: CORTEX_JTAG_DEBUG_PTH_NS; 2X5-PTH-1.27MM-NO_SILK
JP2: CONN_10SMD_COMBO-FEMALE; 1X10_SMD_COMBINED
JP10: CONN_08SMD-COMBO-FEMALE; 1X08_SMD_COMBINED
JP11: JP11; 1X08_SMD_COMBINED
JP13: CONN_06SMD-STRAIGHT-COMBO-FEMALE; 1X06_SMD_STRAIGHT_COMBO
LED1: BLUE; LED-1206
LED3: Yellow; LED-1206
R1, R9, R10, R21, R22: 4.7k; 0603
R5, R20: 100k; 0603
TP1, TP2, TP3, TP4, TP5, TP6: TEST-POINT3X5; PAD.03X.05
TP8: TEST-POINT3; PAD.03X.03
U5: 32MBit; SO08
U6: MK22FN128VLH10; LQFP-64

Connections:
3.3V: C2.1, C6.1, C7.1, C8.1, C11.1, C13.1, C14.1, C17.1, C18.1, C19.1, C20.1, C21.1, C22.1, C27.1, C28.1, C29.1, C30.1, I2C.2, J4.2, J5.1 (VCC), JP10.5, JP10.5@2 (5), JP10.7, JP10.7@2 (7), R5.2, R20.2, R21.2, R22.2, TP1.P$1, U5.8 (VCC), U6.3 (VDD), U6.7 (USBVDD), U6.13 (VDDA), U6.14 (VREFH), U6.21 (VBATT), U6.26 (PTA4/LLWU_P3), U6.30 (VDD), U6.48 (VDD); also elsewhere on the board
5V: JP10.4, JP10.4@2 (4), TP8.P$1; also elsewhere on the board
!RESET: J5.10 (!RESET), JP10.6, JP10.6@2 (6), U6.64 (PTD7); also elsewhere on the board
!WAKE: JP10.8, JP10.8@2 (8); also elsewhere on the board
D+: U6.5 (D+); also elsewhere on the board
D-: U6.6 (D-); also elsewhere on the board
DBG_RESET: R20.1, TP2.P$1, U6.34 (RESET_B)
DBG_SWDCLK: TP5.P$1, U6.22 (PTA0)
DBG_SWDIO: TP4.P$1, U6.25 (PTA3)
DBG_SWO: TP6.P$1, U6.24 (PTA2)
GND: C2.2, C6.2, C7.2, C8.2, C11.2, C13.2, C14.2, C17.2, C18.2, C19.2, C20.2, C21.2, C22.2, C27.2, C28.2, C29.2, C30.2, J4.1, J5.3 (GND), J5.5 (GND), J5.9 (GNDDTCT), JP2.4A (4), JP2.4B (4), JP10.2, JP10.2@2 (2), JP10.3, JP10.3@2 (3), LED1.C, TP3.P$1, U5.4 (GND), U6.4 (GND), U6.15 (VREFL), U6.16 (VSSA), U6.31 (GND), U6.47 (GND); also elsewhere on the board
IO0: JP2.10A (10), JP2.10B (10); also elsewhere on the board
IO1: JP2.9A (9), JP2.9B (9); also elsewhere on the board
IO2: JP2.8A (8), JP2.8B (8); also elsewhere on the board
IO9: JP13.2; also elsewhere on the board
IO10: JP13.3; also elsewhere on the board
IO11: JP13.4; also elsewhere on the board
IO18: JP11.3, JP11.3@2 (3); also elsewhere on the board
IO19: JP11.4, JP11.4@2 (4); also elsewhere on the board
IO20: JP11.5, JP11.5@2 (5); also elsewhere on the board
IO21: JP11.6, JP11.6@2 (6); also elsewhere on the board
IO22: JP11.7, JP11.7@2 (7); also elsewhere on the board
IO23: JP11.8, JP11.8@2 (8); also elsewhere on the board
unnamed: LED1.A, R1.2
unnamed: I2C.3, R10.2
unnamed: I2C.1, R9.2
unnamed: LED3.A, R22.1
unnamed: D5.A, R21.1
QSPI_0: U5.5 (MOSI/IO0); also elsewhere on the board
QSPI_1: U5.2 (MISO/IO1); also elsewhere on the board
QSPI_2: U5.3 (WP#/IO2); also elsewhere on the board
QSPI_3: R5.1, U5.7 (HOLD#/IO3); also elsewhere on the board
QSPI_CS: U5.1 (CE#); also elsewhere on the board
QSPI_SCK: U5.6 (SCK); also elsewhere on the board
RXI: JP11.1, JP11.1@2 (1), LED3.C, U6.40 (PTB17); also elsewhere on the board
SCL: J4.4, JP2.1A (1), JP2.1B (1), JP13.6, R9.1; also elsewhere on the board
SDA: J4.3, JP2.2A (2), JP2.2B (2), JP13.5, R10.1; also elsewhere on the board
SPI_MISO: JP2.6A (6), JP2.6B (6); also elsewhere on the board
SPI_MOSI: JP2.7A (7), JP2.7B (7); also elsewhere on the board
SPI_SCK: JP2.5A (5), JP2.5B (5), R1.1; also elsewhere on the board
TCK: J5.4 (SWDCLK/TCK), U6.62 (PTD5); also elsewhere on the board
TDI: J5.8 (NC/TDI), U6.59 (PTD2/LLWU_P13); also elsewhere on the board
TDO: J5.6 (SWO/TDO), U6.2 (PTE1/LLWU_P0); also elsewhere on the board
TMS: J5.2 (SWDIO/TMS), U6.63 (PTD6/LLWU_P15); also elsewhere on the board
TXO: D5.C, JP11.2, JP11.2@2 (2), U6.39 (PTB16); also elsewhere on the board
VIN: JP10.1, JP10.1@2 (1); also elsewhere on the board

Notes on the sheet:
Qwiic
Headers
Programming Headers
32MBit QSPI Flash
Capacitors
Andrew England
v10
USB -> JTAG
Close this jumper if your I2C slave does not have it's own pullup resistors



Board: 2 copper layers, 68.6 x 53.3 mm, 138 parts (11 on the bottom side), 61 nets.

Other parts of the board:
U$1: (QWIIC)
U$2: #324
U$3: #522
U$4: #621
U$8: SEGGERLOGO#PNG
U$9: #918
U$11: I2C0
U$14: #1017
U$15: #1116
U$17: #1710
U$18: #1812
U$19: #1911
U$20: #RESET2
U$21: #SCL#1926
U$22: #SDA#1827
U$23: #WAKE0
U$24: 3V33
U$25: 5V4
U$26: 158
U$27: 169
U$28: 225
U$29: 423
U$30: 720
U$31: 819
U$32: 1215
U$33: 1314
U$34, U$35, U$36: GND5
U$37: IOREF1
U$38, U$43: NC7
U$39: RXI29
U$40: TXO28
U$41: VIN6
U$42: _#PWM30
U$45: 133
U$46: PWR0
U$47: RXI1
U$48: TXO2
U$49: RESET0
U$50: WAKE1
U$52: REDFIVE_LOGO#05#PNG

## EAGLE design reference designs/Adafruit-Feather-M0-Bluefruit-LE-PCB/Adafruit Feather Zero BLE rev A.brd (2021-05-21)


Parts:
C1, C7, C14: 1uF; 0603-NO
C2, C4: 22pF; 0603-NO
C3, C6, C8: 10µF; 0805-NO
C5, C9: 10uF; 0805-NO
CHG: ORANGE; CHIPLED_0805_NOOUTLINE
D1: MBR120; SOD-123
D2: RED; CHIPLED_0805_NOOUTLINE
D3: BLUE; CHIPLED_0805_NOOUTLINE
JP1: HEADER-1X16ROUND; 1X16_ROUND
JP3: HEADER-1X12; 1X12_ROUND
L: RED; CHIPLED_0805_NOOUTLINE
R1, R3: 100k; 0603-NO
R2: 1K; 0603-NO
R4, R7, R10: 2.2K; 0603-NO
R6: 100K; 0603-NO
R8: 10K\; 0603-NO
SW1: SPST_TACT-KMR2; KMR2
TP1, TP2: TESTPOINTROUND1.5MM; TESTPOINT_ROUND_1.5MM
TP3: SWCLK; PAD-1.5X2.0
TP4, TP5: SWDIO; PAD-1.5X2.0
U1: MBT40; BLE_MODULE_RAYTAC_MDBT40
U2: AP2112-3.3; SOT23-5
U3: MCP73831T-2ACI/OT; SOT23-5
U$4: ATSAMD21G18_QFN; TQFN48_7MM
U$31, U$32: MOUNTINGHOLE2.5; MOUNTINGHOLE_2.5_PLATED
U$34, U$35: FIDUCIAL""; FIDUCIAL_1MM
X1: JSTPH; JSTPH2
X2: 32.768; XTAL3215
X3: microUSB; 4UCONN_20329_V2

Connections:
!RESET: JP1.16, SW1.1, SW1.3 (P1), U$4.40 (/RESET)
+3V3: C5.1, C7.1, C8.1, C9.1, JP1.15, U1.3 (AVDD), U1.14 (VDD), U2.5 (OUT), U$4.6 (VDDA), U$4.17 (VDDIO), U$4.36 (VDDIO), U$4.44 (VDDIN)
A0: JP1.12, U$4.3 (PA02/EINT2/AIN0/Y0/VOUT)
A1: JP1.11, U$4.7 (PB08/I8/AIN2/SERCOM4.0)
A2: JP1.10, U$4.8 (PB09/I9/AIN3/SERCOM4.1)
A3: JP1.9, U$4.9 (PA04/EINT4/VREFB/AIN4/SERCOM0.0)
A4: JP1.8, U$4.10 (PA05/EINT5/AIN5/SERCOM0.1)
A5: JP1.7, U$4.47 (PB02/I2/AIN10/SERCOM5.0)
AREF: C14.1, JP1.14, U$4.4 (PA03/EINT3/VREFA/AIN1)
BLE_SWCLK: TP3.P$1, U1.36 (SWCLK)
CONNECTED: R10.1, U1.39 (P0.19)
D0: JP1.3, U$4.16 (PA11/I11/AIN19/SERCOM0+2.3/I2SF0)
D1: JP1.2, U$4.15 (PA10/I10/AIN18/SERCOM0+2.2/I2SCK)
D2: U$4.23 (PA14/I14/SERCOM2+4.2)
D3: U$4.14 (PA09/I2C/I9/AIN17/SERCOM0+2.1/I2SMC)
D4_SWDIO/RST: TP4.P$1, U1.35 (SWDIO/NRESET), U$4.13 (PA08/I2C/AIN16/SERCOM0+2.0/I2SD1)
D5: JP3.10, U$4.24 (PA15/I15/SERCOM3+4.3)
D6: JP3.9, U$4.29 (PA20/I4/SERCOM3+5.2/I2SSC)
D7_BLE_IRQ: U1.8 (P0.25), U$4.30 (PA21/I5/SERCOM3+5.3/I2SFS0)
D8_BLE_CS: U1.7 (P0.24), U$4.11 (PA06/EINT6/AIN6/SERCOM0.2)
D9: JP3.8, R3.2, R6.1, U$4.12 (PA07/I7/AIN7/SERCOM0.3/I2SD0)
D10: JP3.7, U$4.27 (PA18/I2/SERCOM1+3.2)
D11: JP3.6, U$4.25 (PA16/I2C/I0/SERCOM1+3.0)
D12: JP3.5, U$4.28 (PA19/I3/SERCOM1+3.3/I2SD0)
D13: JP3.4, R7.1, U$4.26 (PA17/I2C/I1/SERCOM1+3.1)
D+: U$4.34 (PA25/I13/SERCOM3+5.3/D+), X3.D+
D-: U$4.33 (PA24/I12/SERCOM3+5.2/D-), X3.D-
DCC: U1.15 (DCC)
DEC2: U1.41 (DEC2)
DFU: JP1.1, U1.24 (P0.07)
EN: JP3.2, R1.2, U2.3 (EN)
FCTRYRST: TP5.P$1, U1.34 (P0.16)
GND: C1.2, C2.2, C3.2, C4.2, C5.2, C6.2, C7.2, C8.2, C9.2, C14.2, D2.C, D3.C, JP1.13, L.C, R6.2, R8.2, SW1.2 (S), SW1.4 (S1), U1.1 (GND), U1.2 (GND), U1.13 (GND), U1.16 (P0.30), U1.25 (GND), U1.42 (GND), U2.2 (GND), U3.2 (VSS), U$4.5 (GNDA), U$4.18 (GND), U$4.35 (GND), U$4.42 (GND), U$4.THERMAL (GND), X1.1, X3.BASE@1 (GND), X3.BASE@2 (GND), X3.GND, X3.SPRT@1 (GND), X3.SPRT@2 (GND), X3.SPRT@3 (GND), X3.SPRT@4 (GND)
MISO: JP1.4, U1.5 (P0.22), U$4.21 (PA12/I12/I2C/SERCOM2+4.0)
MODE: R4.1, U1.38 (P0.18)
MOSI: JP1.5, U1.6 (P0.23), U$4.19 (PB10/I10/SERCOM4.2/I2SMC)
unnamed: CHG.C, R2.1
unnamed: L.A, R7.2
unnamed: R2.2, U3.1 (STAT)
unnamed: R8.1, U3.5 (PROG)
unnamed: C2.1, U$4.1 (PA00/EINT0/SERCOM1.0), X2.P$1
unnamed: D2.A, R4.2
unnamed: C4.1, U$4.2 (PA01/EINT1/SERCOM1.1), X2.P$2
unnamed: D3.A, R10.2
SCK: JP1.6, U1.4 (P0.21), U$4.20 (PB11/I11/SERCOM4.3/I2SCL)
SCL: JP3.11, U$4.32 (PA23/I2C/I7/SERCOM3+5.1/SOF)
SDA: JP3.12, U$4.31 (PA22/I2C/I6/SERCOM3+5.0)
SWCLK: TP1.P$1, U$4.45 (PA30/I10/SECOM1.2/SWCLK)
SWDIO: TP2.P$1, U$4.46 (PA31/I11/SECOM1.3/SWDIO)
VBAT: C3.1, D1.A, JP3.1, R3.1, U3.3 (VBAT), X1.2
VBUS: C6.1, CHG.A, D1.C, JP3.3, R1.1, U2.1 (IN), U3.4 (VDD), X3.VBUS
VDDCORE: C1.1, U$4.43 (VDDCORE)

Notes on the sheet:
POWER AND FILTERING
RESET
10K = 100mA
5.0K = 200mA
2.0K = 500mA
1.0K = 1000mA
N/C
TXLED
USBHOSTEN
RXLED
TXD
RXD
BLUEFRUIT LE MODULE (nRF51)
ATSAMD21
USB & Batt Charging
Breakouts & D13 LED



Board: 2 copper layers, 50.8 x 22.9 mm, 46 parts (7 on the bottom side), 48 nets.

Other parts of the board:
U$7: ADAFRUIT_3.5MM
U$9: FEATHERLOGO
U$25: PCBFEAT-REV-040
U$26: BLUEFRUITLOGO_100MM

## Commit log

2021-03-20 SiFive Hifive Rev. B BOM/Sch/Brd pdfs and altium files. FE310-G002 Datasheet and Manual.
    [Cover.SchDoc, Debug.SchDoc, Freedom_E310.SchDoc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]
2021-05-21 Added Sparkfun RED-V reference design, including BOM and library
    [SparkFun RED-V RedBoard.brd, SparkFun RED-V RedBoard.sch]
2021-05-21 Created initial Athena library from parts imported from Sparkfun Red-V and Adafruit Feather designs. Updated README. Added Adafruit reference design.
    [Adafruit Feather Zero BLE rev A.brd, Adafruit Feather Zero BLE rev A.sch, Cover.SchDoc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]
2021-05-26 Initial work on the power supply portion of the schematic
    [Athena-r0p1.sch]
2021-05-26 Initial work on the MCU portion of the schematic incl. oscillators and flash
    [Athena-r0p1.sch]
2021-05-26 Initial work on the USB-JTAG portion of Nest. Added PWR/JTAG header to separate Owl and Nest. Pdf of RedBoard schematic reference added for ease of viewing
    [Athena-r0p1.sch]
2021-06-01 Athena Rev. 0.1 Schematic complete.
    1. Switched out oscillators to match the parts used in HiFive
    2. Cleaned and commented the schematics
    3. Completed the header pinout
    4. Removed unused parts from the library
    5. Added datasheets for all non-passives
    [Athena-r0p1.sch]
2021-06-05 Started on the board design. IC and header placement, GND and 3.3V layer polygon pours. The long I/O headers are limiting board size. Switch to short double column headers?
    [Athena-r0p1.brd]
2021-06-28 Initial work on addressing Erik's feedback of r0p1
    [Athena-r1p0.sch]
2021-06-28 Continued work on addressing Erik's comments, specifically, removing the NCP1117. Also changed out the TVS diodes to the devices in the HiFive design.
    [Athena-r1p0.sch]
2021-08-05 Implementing changes suggested by Erik and Ashish during July schematic review
    [Athena-r1p0.sch]
2021-08-06 Finished updates based on design review feedback. Added mounting holes and chassis GND. Converted all passives to 0402. Renumbered all parts. Added cover page. Replaced SiTime oscillator with std foo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
    [Athena-r1p0.sch]
2021-08-17 First pass at Athena layout. Passes all DRC except for issues with the USB port pads (which is a MF housepart)
    [Athena-r1p0.brd, Athena-r1p0.sch]
2022-05-19 Updated design
    Removed off-board debug header
    [Athena-r1p0.brd, Athena-r1p0.sch]
2022-06-06 Athena A1 initial design pre-review
    [Athena-A1.brd, Athena-A1.sch]
2022-07-11 Updates post-review in progress
    Sch: added power switch, improved symbols, added cap on Wake, added 0Ohm res to crystal, mikro gpio instead of wake/reset
    Brd: moved tag connect to top, added clearance for mikro click brds, routed new switch, etc.
    Todo: silkscreen cleanup and checking
    [Athena-A1.brd, Athena-A1.sch]
2022-07-25 Finished updates post-review
    [Athena-A1.brd, Athena-A1.sch]
2022-07-25 Moved pours outside dimension
    [Athena-A1.brd, Athena-A1.sch]
2022-10-01 Athena A1 final
    Minor board cleanup
    [Athena-A1.brd, Athena-A1.sch]
2022-10-01 Athena A1 final (for real, now)
    Fixed some text that got moved over pours and one trace with a weird angle
    [Athena-A1.brd]

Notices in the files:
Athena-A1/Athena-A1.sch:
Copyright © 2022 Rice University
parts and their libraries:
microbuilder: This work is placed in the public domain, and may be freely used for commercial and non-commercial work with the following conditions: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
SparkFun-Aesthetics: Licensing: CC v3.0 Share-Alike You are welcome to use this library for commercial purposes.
